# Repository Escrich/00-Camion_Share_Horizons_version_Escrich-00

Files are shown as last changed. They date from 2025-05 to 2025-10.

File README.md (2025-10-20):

# Camion Share Horizons versión Escrich

<br>
<p align="left">
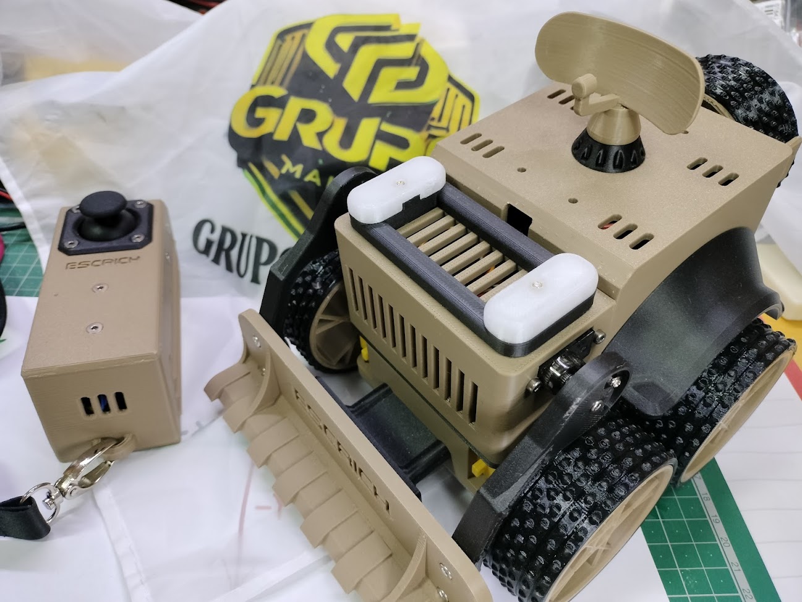
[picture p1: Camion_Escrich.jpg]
Camión Escrich

</p>
<br>

Bueno, tal como prometí, este es el repositorio de GitHub, donde he puesto todas las modificaciones, o al menos las que he recordado, que le he hecho al camión de Share Horizons.

La idea de mejorar, (desde mi punto de vista), el camión, no es porque fuese un mal diseño, sino, porque pensé que había ciertas cosas que con pequeñas modificaciones podrían funcionar aún mejor, 
lo cual era una buena excusa para ponerse a jugar, y crear piezas nuevas y buscarme así, nuevos problemas.

Aquí os traigo los diseños modificados, los he grabado en formato .step, porque es un buen formato de intercambio, que pueden abrir la mayoría de programas de diseño, e incluso directamente los laminadores, 

- 20250603 He añadido imagenes en cada sección, para ver de una manera mas rápida y eficiente, lo que esa sección contiene.
- 20250603 He subido las piezas en formato .stl u .obj, para que sea aún mas facil imprimirlas, recuerda que tu laminador, el que sea, procesa perfectamente los ficheros .obj tal como lo hace con los ficheros .stl.
- 20250603 Mejora de las instrucciones y tareas a efectuar con el mando a distancia.
- 20250827 Actualización del software del camión y del mando a distancia, como consecuencia de las nuevas actualizaciones en las librerías de Arduino.

> [!TIP]
> La mayor parte de la información está en la zona de notas de trabajo, donde la mayoría de las notas  que escribí a mano sobre el papel, las he volcado sobre el PDF original, tambien hay información especifica en cada una de las secciones.

> [!IMPORTANT]
> La sección sobre el nuevo mando a distancia, constituye un nuevo proyecto por si sola, en esa sección, al igual que en muchas otras, hay mucho material didactico, que puede ser muy util a los que estén empezando en el mundo del DIY, así como para ser usado incluso a nivel escolar, o en grupos de formación, he intentado en todo, ser lo mas didactico posible.

> [!NOTE]
> Toda la información del proyecto original, está en:
> 
> https://makerworld.com/es/models/903977#profileId-863654
>
> https://cad.onshape.com/documents/0da7019aae1737c3977f49da/w/1bc25fe6fd6783f9f0ffa83a/e/cbea3b41cde89c5ffeedc16a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
>
> https://www.youtube.com/shorts/hSA0gdp2WEo
>
> https://www.youtube.com/@SHAREHORIZONS

<br>
<br>

- **Bueno, este es un trabajo que he hecho, pensando en que pueda servir de ayuda a los demás, si a alguien le sirve este trabajo, para no perder el tiempo que yo he necesitado perder, aunque sea uno solo, ya me doy por satisfecho, entonces mi objetivo se habrá cumplido, si necesitas ayuda, tienes dudas, o quieres comentar algo al respecto, además de que puedes hacerlo directamente aquí, recuerda que puedes encontrarme en las redes, y que estas son mis direcciones:**

<br>
 
www.github.com/escrich

https://t.me/escrich

https://www.tiktok.com/@josemescrich

https://www.youtube.com/@josem.escrich2610

<sub>
20251020 Jose M. Escrich 
</sub>

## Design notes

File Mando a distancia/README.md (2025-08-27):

# Mando a distancia Escrich

<br>
<p align="left">
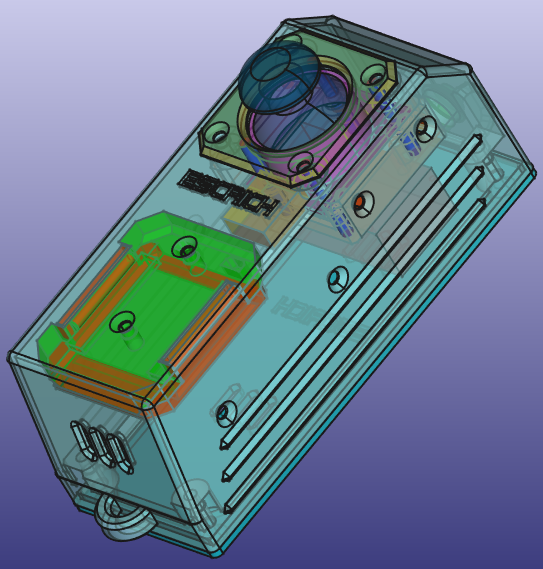
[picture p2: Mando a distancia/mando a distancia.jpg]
Mando a distancia versión Escrich

</p>
<br>

Aquí podeis encontrar toda la información relativa al mando a distancia, desde el programa, lleno de comentarios con los cambios efectuados, y una explicacion de dichos cambios, en la mayoría de los casos, 
hasta las instrucciones de montaje y puesta en marcha, paso a paso.

Tambien están, por supuesto, los ficheros .step de todas las piezas que componen el mando a distancia, así como los ficheros .obj o .stl, pero lo que mas trabajo me ha costado, 
es la guía de construcción, donde se explica paso a paso como construirlo, como y cuando programarlo, y como cablearlo, ajustarlo y hacerlo funcionar.

La forma de programarlo, que está descrita paso a paso, es la descrita en el documento original de **Share Horizons**, y es exactamente la misma que para el **DOIT ESP32 DEV KIT V1**, pero eligiendo una placa, o la otra, ya que el microcontrolador que lleva dentro, 
un **Wemos D1 Mini ESP32**, es **100% compatible**, con el **ESP32** del diseño original.

Programarlo, es tan simple como conectar un cable USB entre tu ordenador y el **Wemos D1 Mini**, cargar el programa que encontrarás aquí, en el entorno **Arduino**, si es que no lo habías hecho antes, 
elegir la placa, (**Wemos D1 Mini ESP32**) y el **puerto correctos**, 
asegurarte de que has puesto la **mac address** de la placa de tu camión correctamente, y pulsar en el entorno **Arduino** el **icono de compilar y cargar**, 
si lo has hecho todo bien, el sistema saldrá andando a la primera, que por otra parte, es lo mas normal.

> [!IMPORTANT]
> 20250827 Actualización del software del mando a distancia, como consecuencia de las actualizaciones de las librerías de Arduino.
>

> [!WARNING]
> Al construir el mando a distancia, no olvides, antes de aplicar tension al Wemos D1 MINI, haber ajustado externamente la fuente de alimentación, para una tensión de salida de entre **5'0 Voltios, y 5'1 Voltios**.
> si no lo haces así, puedes destruir el microcontrolador, al aplicarle una tensión mas alta de la que puede aguantar.

<br>

> [!CAUTION]
> Recuerda alimentar al Joystick con tan **solo 3'3 Voltios**, desde los pines de la placa del Wemos, o ESP32,
> Es un problema muy común, alimentarla a 5 voltios, tal como pone en su serigrafía, haciendolo así, el camión se pondrá en marcha en cuanto conecte con el mando, y notarás una sensación de total falta de control.

<br>
 
www.github.com/escrich
  
https://t.me/escrich
  
https://www.tiktok.com/@josemescrich

<sub> 
20250509 Jose M. Escrich 
</sub>

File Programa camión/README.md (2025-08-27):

# Programa del camión Share Horizons versión Escrich

<br>
<p align="left">
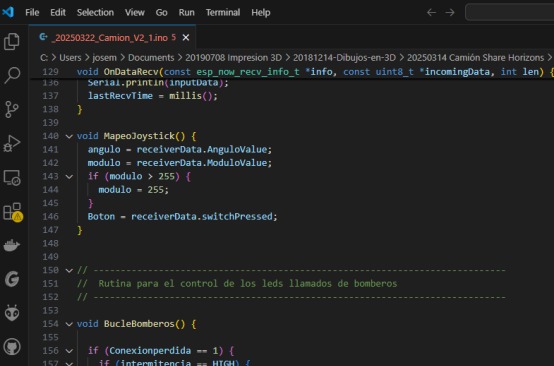
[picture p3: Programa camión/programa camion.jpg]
Programa del Camión

</p>
<br>

Aquí podeis encontrar información relativa al programa del camión, una vez reformado por mi, que insisto, no es mejor ni peor, tan solo diferente al original, y que conserva una buena parte de lo que ya había.

- La forma de programarlo, que está descrita paso a paso, es exactamente la misma para el DOIT ESP32 DEV KIT V1, que para el Wemos D1 Mini ESP32, que es el micro que lleva mi versión del mando a distancia,
  una vez en el entorno Arduino, solo hay que elegir la placa y puerto correctos, hay una buena descrpcion de como hacerlo en las instrucciones del mando a distancia. 

- Por cierto el Wemos D1 Mini ESP32, es 100% compatible, con el ESP32 del diseño original.

- Programarlo es tan simple como conectar un cable USB entre tu ordenador y el ESP32, cargar el programa que encontrarás aquí, en el entorno Arduino, si es que no lo habías hecho antes, 
elegir la placa, (DOIT ESP32 DEV KIT V1) y el puerto correctos, 
y pulsar en el entorno Arduino el icono de compilar y cargar, 
si lo has hecho todo bien, el sistema saldrá andando a la primera, que por otra parte, es lo mas normal.

 - En esta versión se ha cambiado, comprobado y corregido, la nomenclatura de todas las variables de dirección y control de motor, para que coincidan con la dirección en la que se mueve el camión.

 - He recalculado los angulos de la dirección, haciendolos simetricos, tanto a izquierda y derecha, como adelante y atrás.

 - Tambien se han añadido rutinas para el cambio de color de los leds en función de la dirección, que ahora al moverse, hay dos leds de la tira, que se vuelven azules, y que indican en que dirección vamos,
   por eso es importante el orden y la forma de montaje, a la hora de poner la tira led, por otra parte, aunque está hecho para 8 leds, es muy sencillo editarlo para que funcione con los 12 leds del diseño original.

 - Añadidos nuevos leds Neopixel en el canal 5, con los que se hace el efecto de luces de policia, son cuatro leds inteligentes Neopixel, 
  conectados uno a continuación de otro, y programados para hacer ese efecto, con una sección de programa abierta a hacer las combinaciones que quieras, como ya digo en otro sitio, es una versión, muy exportable a cualquier otro proyecto.

 - También puedes desde el mismo programa, sin necesidad de un programa auxiliar, mostrar la dirección Mac Address de tu camión, imprescindible para incluirla en el programa del mando a distancia

 - Otra cosa que tambien he añadido, tanto en el mando como en el camión, es una cosa mas bien estética, el led azul de la placa, ahora,
   se enciende o apaga a cada ciclo de programa, para poder comprobar de manera visual, que el programa está funcionando y no se ha quedado colgado.

> [!IMPORTANT]
> 20250827 Actualización del software del camión, como consecuencia de las actualizaciones de las librerías de Arduino
>

> [!TIP]
> Aunque aquí te deje alguna explicación sobre el software del camión, la mayor parte de las reformas, por no decír todas,
> están comentadas y documentadas con texto y comentarios, dentro del propio programa, (no me gusta llamarle "sketch")
>

<br>

www.github.com/escrich
  
https://t.me/escrich
  
https://www.tiktok.com/@josemescrich

<sub> 
20250509 Jose M. Escrich 
</sub>

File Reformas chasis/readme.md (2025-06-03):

# Reforma del chasis

<br>
<p align="left">
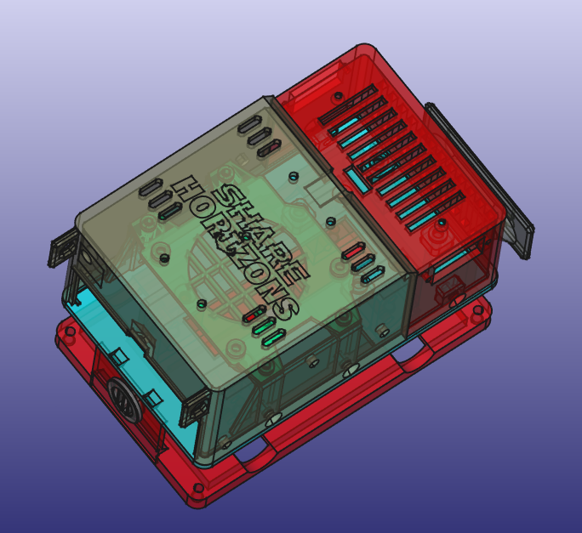
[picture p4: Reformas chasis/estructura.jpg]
Estructura, chasis y demás elementos mecánicos

</p>
<br>

Esta es la parte mas visible, ya que además engloba las las piezas de mayor tamaño, las reformas que he hecho a las diferentes piezas, han sido las siguientes:

- **Chasis V1;** En primer lugar empezamos por el propio chasis, las reformas efectuadas en el han sido varias, la primera, y mas importante, fué suplementar en 3 milimetros la posición de los motores,
  para que queden mas afuera, mejore la estabilidad, e impida que los laterales de las ruedas rocen en la estructura del camión.
  tambien se le ha hecho un pequeño espacio, para poner una matricula, las rejillas originales, que en alguno de los prototipos hemos llegado a romper, y eliminar para poner el interruptor principal,
  interruptor que finalmente hemos montado en otro sitio, son sustituidas por un pequeño tapón en forma de rejilla, que se puede imprimir aparte, y que tambien está incluido en el fichero .step.
  
- **Defensa V1;** Aquí la reforma ha sido tan simple, como añadir un espacio para la matricula delantera, el diseño de la pieza me parece bueno tal como está.

- **Estructura interna;** Aquí el cambio ha sido mayor, en primer lugar se han añadido paredes y angulos, entre las antiguas torretas verticales, que por su posición y forma, eran demasiado fragiles y faciles de romper,
  también se han añadido separadores, para la placa de circuito impreso, en la zona donde se atornilla la placa del driver para los motores, con el objeto de que al atornillarla,
  las soldaduras de las conexiones inferiores, no ejerzan presión contra el plastico de las torretas cuadradas.

- **Rejilla tapón;** Esta es la rejilla descrita anteriormente, para sustituir a la rejilla trasera del chasis, aumenta la resistencia de esa zona, bastante endeble, y permite dar un toque de diferente color.

- **Base ESP32;** Aquí he añadido rejillas para ventilación del ESP32, tambien he cambiado el sistema de insertos metalicos, que ahora se montan por la parte contraria al circuito impreso,
   tambien he diseñado unas pequeñas torretas, para que la parte inferior del circuito impreso, y sus soldaduras, no haga, presión contra la pieza que lo soporta,
   sino que ahora hay un espacio que permite la ventilación, al tiempo que elimina el contacto con la superficie de la propia pieza de soporte.
 
- **Soporte servos;** En esta pieza, los cambios están relacionados con las luces de "Policia", se trata de los taladros para sujetar la estructura de las luces led,
  o cualquier otra cosa, así como la salida de cables de las propias luces, hacia el interior del camión.

- **Carcasa multiusos;** Denominada así por sus multiples taladros para montar cualquier arilugio, así como sus otras peculiaridades, en primer lugar, al montar el soporte del ESP32 girado 180 grados,
  como digo en mis notas, la carcasa tiene un recorte en la parte delantera, que permite, siempre que no esté montado el soporte de servos, conectar y cambiar el programa del ESP32,
  aunque esta carcasa esté puesta, con lo que se ahorra desmontar todas las ruedas, y quitar la carcasa, para introducir cambios en el programa, pensé también en usar una conexión OTA, pero eso de momento está parado.

  Otra caracteristica importante son las multiples rejillas de ventilación, ya que por su forma de cúpula, tiende a almacenar el calor en la zona del ESP32, con las rejillas se evita, al menos en parte, este efecto.

  tambien tiene en la parte trasera dos protecciones, una a cada lado, que protegen el interruptor de palanca, y la toma para poder cargar la batería sin tener que abrir la puerta o el camión,
  simplemente, se conecta la clavija del cargador, con el interruptor en la posición de apagado, y se pone en marcha el cargador.

  Con el fin de poder usar interruptores de palanca, para taladro de 6 mm., he añadido un separador, que se monta internamente, y hace que el interruptor asome lo justo como para ponerle la tuerca.
 
- **Placa motores;** Por ultimo, para los que ya tengan el camión impreso, he añadido esta pequeña placa con dos taladros, de la que hay que imprimir cuatro unidades, y que se monta en el diseño original,
  entre cada motor y el chasis, y que hace de suplemento, para conseguir separar las ruedas del chasis, tal como describía al principio de este texto. 

<br>

www.github.com/escrich
  
https://t.me/escrich
  
https://www.tiktok.com/@josemescrich

<sub> 
20250510 Jose M. Escrich 
</sub>

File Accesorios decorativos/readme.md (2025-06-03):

# Accesorios añadidos o modificados

<br>
<p align="left">
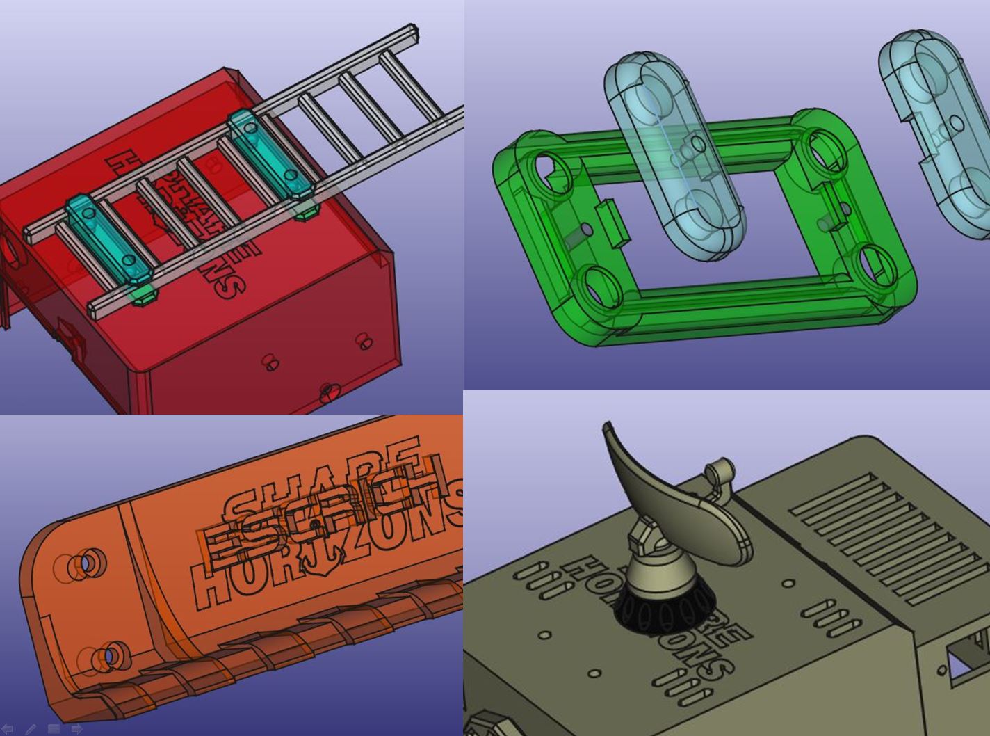
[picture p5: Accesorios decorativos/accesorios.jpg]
Accesorios decorativos

</p>
<br>

### Pala excavadora

Esta pala se basa totalmente en el diseño original, tan solo se le han añadido los dientes, y se han movido hacia el centro los dos grupos de taladros de sujección, disminuyendo la distancia entre taladros en ocho milimetros, 
esta diferencia de ocho milimetros de envergadura, proviene de un exceso en la medida original, y del hecho de haber rebajado el brazo del servo, por el lado contrario al piñon, hasta dejarlo plano.

En ambos camiones está impresa en Super PLA plus.

### Escalera de bomberos

La escalera es para aprovechar el color rojo de uno de mis dos camiones, para darle un aspecto similar al de un camión de bomberos, lejos de pretender una recreación realista, es mas bien algo conceptual, o casi un elemento de comic,
junto a la escalera están los soportes que la sujetan y acompañan, en los soportes de la parte superior, se montan insertos metálicos de M3 usando calor, estos insertos, se montan desde lo que sería la parte superior, 
por contra el tornillo que los sujeta, viene desde dentro de la carcasa del camion, haciendo, según mi practica habitual, que los insertos queden de forma antagonista al tornillo,
y que no sea posible arrancarlos, por mas que se apriete el mencionado tornillo, sino que la tendencia, sea a clavarse cada vez mas en la pieza, evitando que se pueda soltar, 
aquí no es necesaria, quizás, tanta sujección, pero es mas un modo de trabajar que aplico siempre que es posible, a todos los insertos metálicos que monto en mis diseños.

La escalera y sus piezas de sujección, han sido impresas en PETG.

### Antena de telecomunicaciones

La antena es solo un adorno que dibujé hace años, como parte de los diseños para un barco de RC, y al igual que en el caso de la escalera es solo un concepto, poco realista, pero entendible, de lo que es una antena
lleva en su interior un inserto metalico de M3, montado a la manera tradicional, para no dejar un taladro visible desde la parte superior, y una pieza decorativa circular como base, 
se atornilla tambien desde dentro del camión, usando la carcasa modificada, que denomino carcasa multiusos, y que tiene ya preparados los taladros para la escalera, la antena o cualquier otro uso que la imaginación te sugiera.

La antena está impresa en Super PLA plus, y la pieza decorativa de la base en PLA con fibra de carbono, (PLA CF).

### Rotativo luminoso

Aunque no hay ningún tipo de rotación mecanica, se trata de un rotativo como el de una ambulancia, o coche de bomberos, donde la sensación de rotación se consigue con el movimiento aparente, que se logra encendiendo y apagando leds del tipo Neopixel,
para ello en el programa se ha añadido un nuevo canal Neopixel, usando D5 como salida de control, y se ha implementado con cuatro leds independientes, no en una tira led, cableados uno a continuación del otro, 
el "rotativo" hace tres funciones diferentes, las dos primeras muy similares, en caso de no haber conexión con el mando, mediante una rutina simple se encienden en rojo, dos a dos, los dos leds delanteros, o los dos traseros, mientras los otros dos permanecen apagados,
una vez que se produce la conexión entre el camión y el mando a distancia, la rutina es la misma, pero esta vez con la luz en verde.
La diferencia real viene al poner los motores en marcha, aquí la estructura del programa es diferente a los dos casos anteriores, y se pueden programar facilmente, multiples pasos con multiples combinaciones de luces y colores, simplemente añadiendo subestructuras case / break,
una vez estas se agoten, el programa simplemente saldrá y si las condiciones se mantienen, volverá a ejecutar toda la secuencia de colores desde el principio.

Tras muchas pruebas, poner luces en plan "coche fantastico", y hacer muchas combinaciones, al final solo hay dos combinaciones de rojo y azul, que se alternan entre si, con lo que el programa de luces en movimiento solo tiene dos pasos, a pesar de mantener la estructura para poder crear multiples pasos y cambios de luz, lo que la convierte en una estructura de programa, facilmente exportable, para poder ser utilizada en otros proyectos.

Todo el conjunto va sujeto con dos tornillos de M2'5, que vienen desde la pieza de soporte de los servos, previamente modificada, con los taladros de sujección y la salida de cables hacia el interior del camión, los insertos de M2'5, se montan en las dos piezas transparentes/translucidas, desde la parte de arriba, para ser atornilladas desde abajo, siguiendo la misma filosofia explicada previamente para los insertos.

Las luces propiamente dichas, en ambos camiones, están impresas en Transparent PETG, y los soportes, en el caso del camión de bomberos es PETG, pero en el caso del camióncito con antena, se trata de nuevo de PLA CF.

### Tapa leds gruesa

Es la misma tapa original, pero aumentada en grosor en un 50%

Está impresa en un solo color, usando transparent PETG

<br>

www.github.com/escrich

https://t.me/escrich

https://www.tiktok.com/@josemescrich

<sub> 
20250510 Jose M. Escrich 
</sub>

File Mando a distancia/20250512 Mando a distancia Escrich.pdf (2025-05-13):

# 20250512 Mando a distancia Escrich

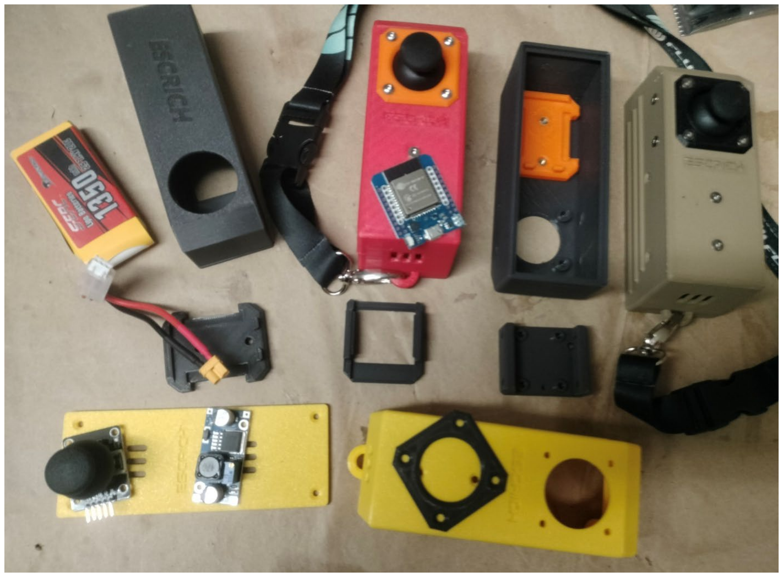
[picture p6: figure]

## Teoría e instrucciones para el mando a distancia multiusos

13/05/2025 | 1 20250512 Mando a distancia Escrich
www.github.com/escrich

## Orientación del Joystick

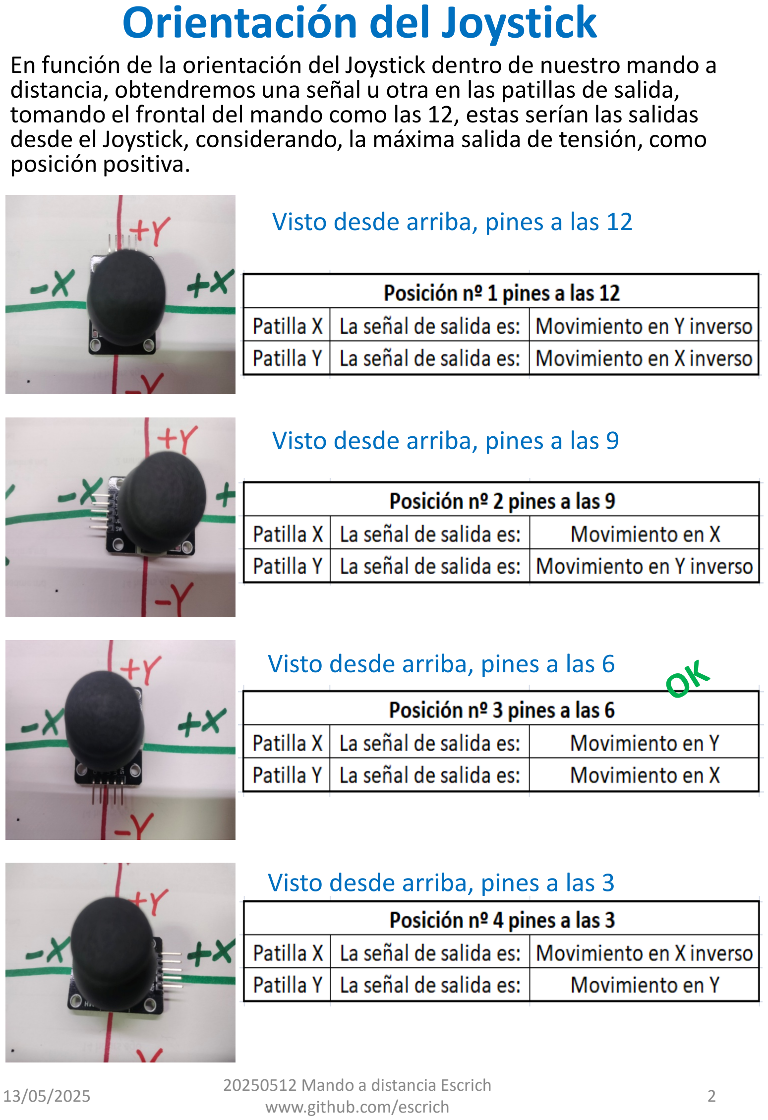
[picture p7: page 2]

Visto desde arriba, pines a las 12

13/05/2025 | 2 20250512 Mando a distancia Escrich

Visto desde arriba, pines a las 9

Visto desde arriba, pines a las 6

Visto desde arriba, pines a las 3

En función de la orientación del Joystick dentro de nuestro mando a distancia, obtendremos una señal u otra en las patillas de salida, tomando el frontal del mando como las 12, estas serían las salidas desde el Joystick, considerando, la máxima salida de tensión, como posición positiva.

## Orientación del Joystick

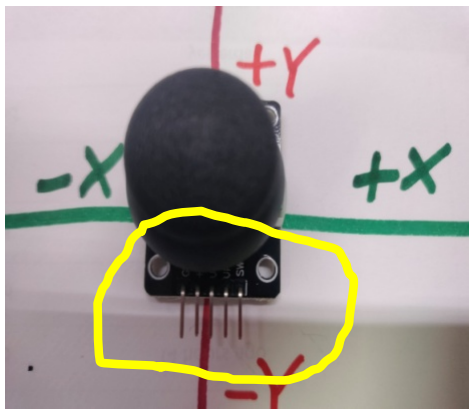
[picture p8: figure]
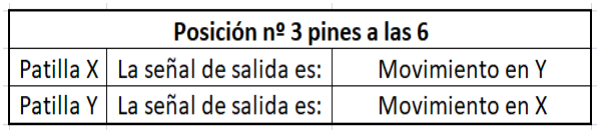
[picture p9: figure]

13/05/2025 | 3 20250512 Mando a distancia Escrich

Al montar los pines mirando hacia nosotros, podemos ver que las funciones de X e Y están intercambiadas, por lo que, o bien las invertimos en el programa, o bien, intercambiamos los cables, para mayor claridad y para poder mantener los mismos esquemas, he optado por hacer los cambios en el programa

Visto desde arriba, pines a las 6

## Conexión del Joystick

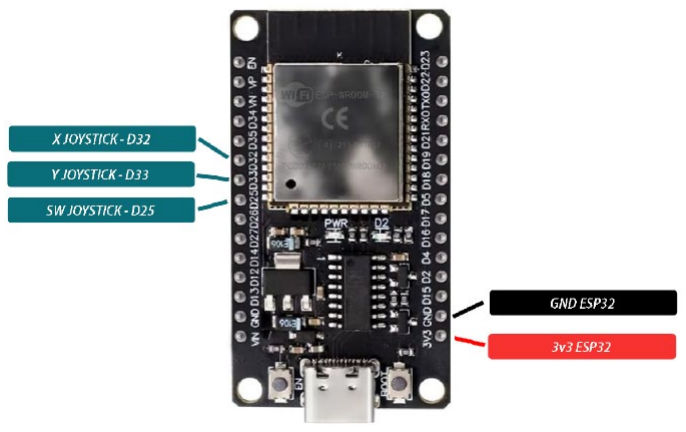
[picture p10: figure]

13/05/2025 | 4 20250512 Mando a distancia Escrich

Por tanto las conexiones quedarían tal como se muestran en las instrucciones de Share Horizons.

Esquema original Share Horizons.

## Conexión del Joystick

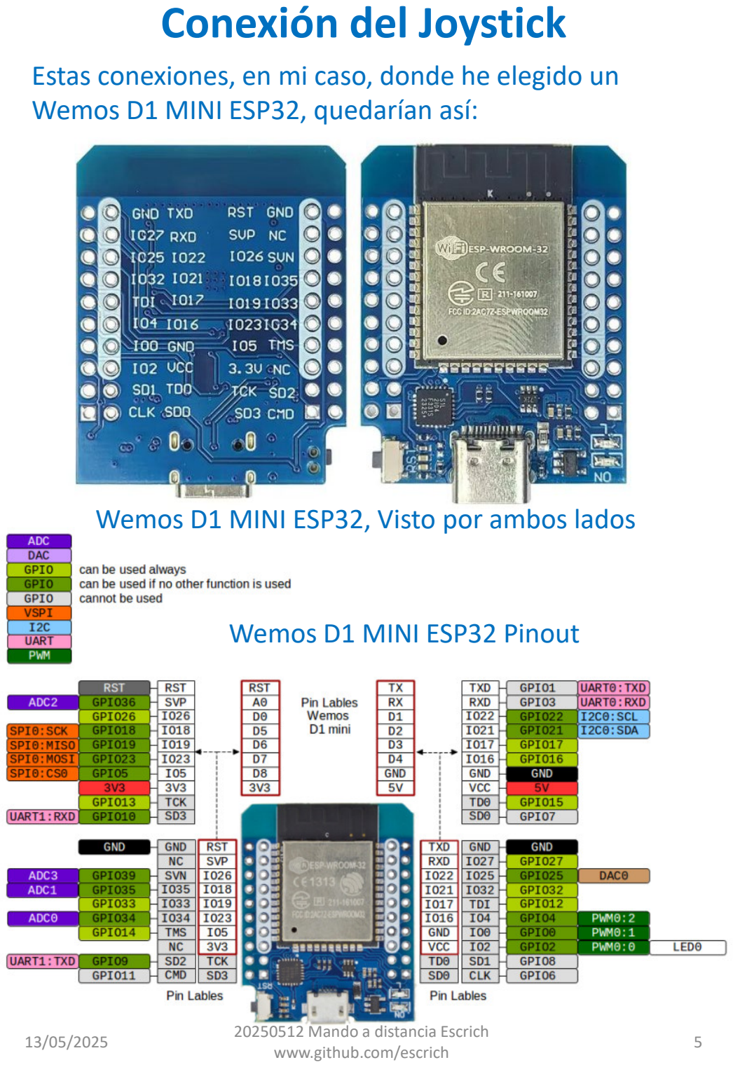
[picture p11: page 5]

13/05/2025 | 5 20250512 Mando a distancia Escrich

Estas conexiones, en mi caso, donde he elegido un Wemos D1 MINI ESP32, quedarían así:

Wemos D1 MINI ESP32 Pinout

Wemos D1 MINI ESP32, Visto por ambos lados

## Conexión del Joystick

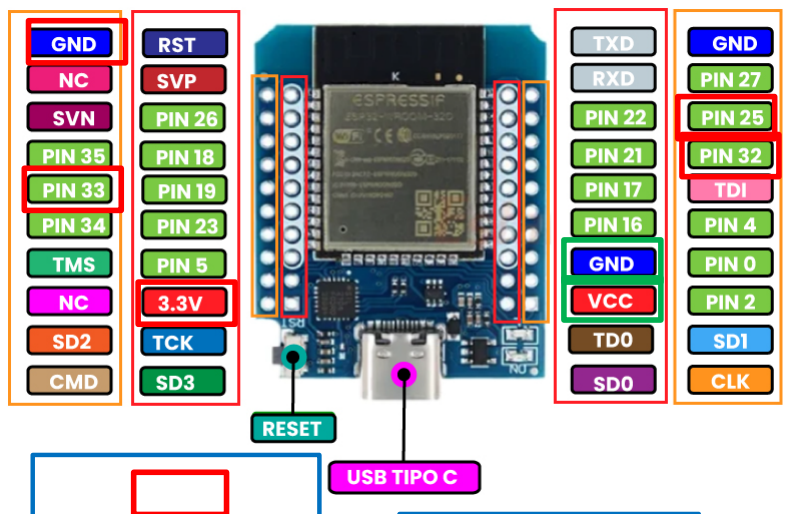
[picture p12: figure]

13/05/2025 | 6 20250512 Mando a distancia Escrich

Estas conexiones, en mi caso, donde he elegido un Wemos D1 MINI ESP32, quedarían así:

Esquema de conexiones

Conexiones al joystick:
D32: EJE X
D33: EJE Y
D25: Switch joystick
GND: Negativo
3.3V: Positivo

Alimentación a la placa:
GND: Negativo
VCC: + 5 Voltios

Haciendo las conexiones según estas instrucciones el mando a distancia es 100% compatible con la versión original de Share Horizons.

## Alimentación del Joystick

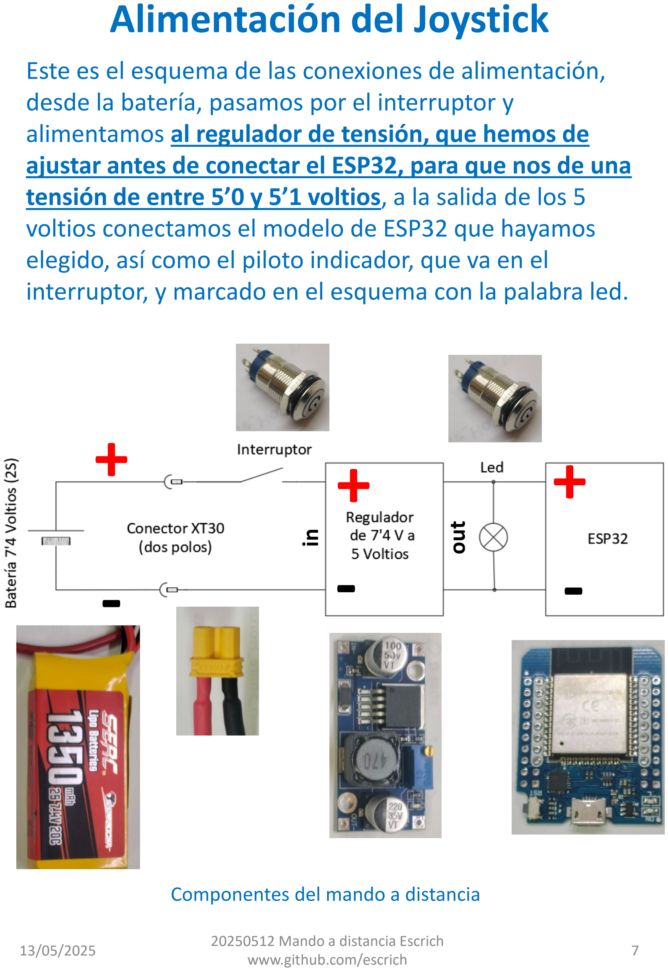
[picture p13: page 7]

13/05/2025 | 7 20250512 Mando a distancia Escrich

Este es el esquema de las conexiones de alimentación, desde la batería, pasamos por el interruptor y alimentamos al regulador de tensión, que hemos de ajustar antes de conectar el ESP32, para que nos de una tensión de entre 5’0 y 5’1 voltios, a la salida de los 5 voltios conectamos el modelo de ESP32 que hayamos elegido, así como el piloto indicador, que va en el interruptor, y marcado en el esquema con la palabra led.

Componentes del mando a distancia

+ | + | +

in

out

## Montaje del mando a distancia

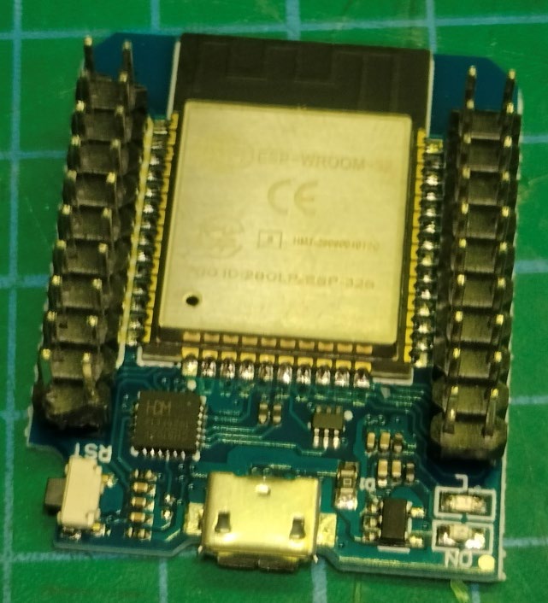
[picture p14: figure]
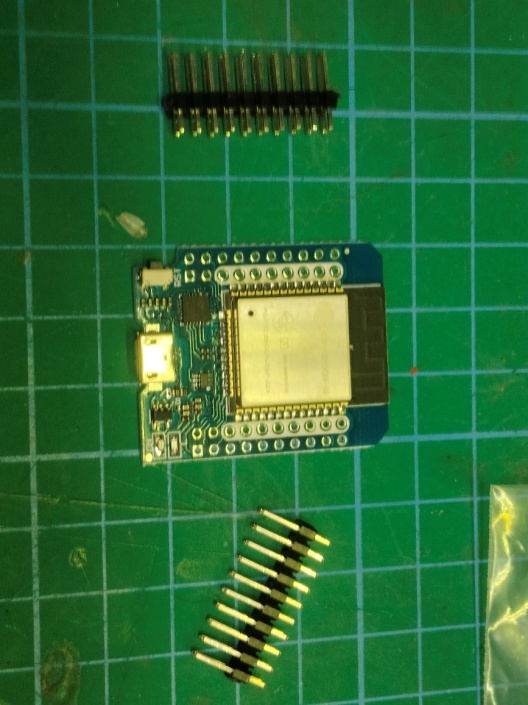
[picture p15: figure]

13/05/2025 | 8 20250512 Mando a distancia Escrich

Lo primero que se necesita, son dos tiras dobles de 10 pins x 2, soldamos las dos tiras de pins de dos filas por la parte de debajo del Wemos, de manera que los pins, para conectar, sobresalgan por el lado donde está el chip principal

Wemos D1 Mini ESP32 con las tiras de pins ya montadas.

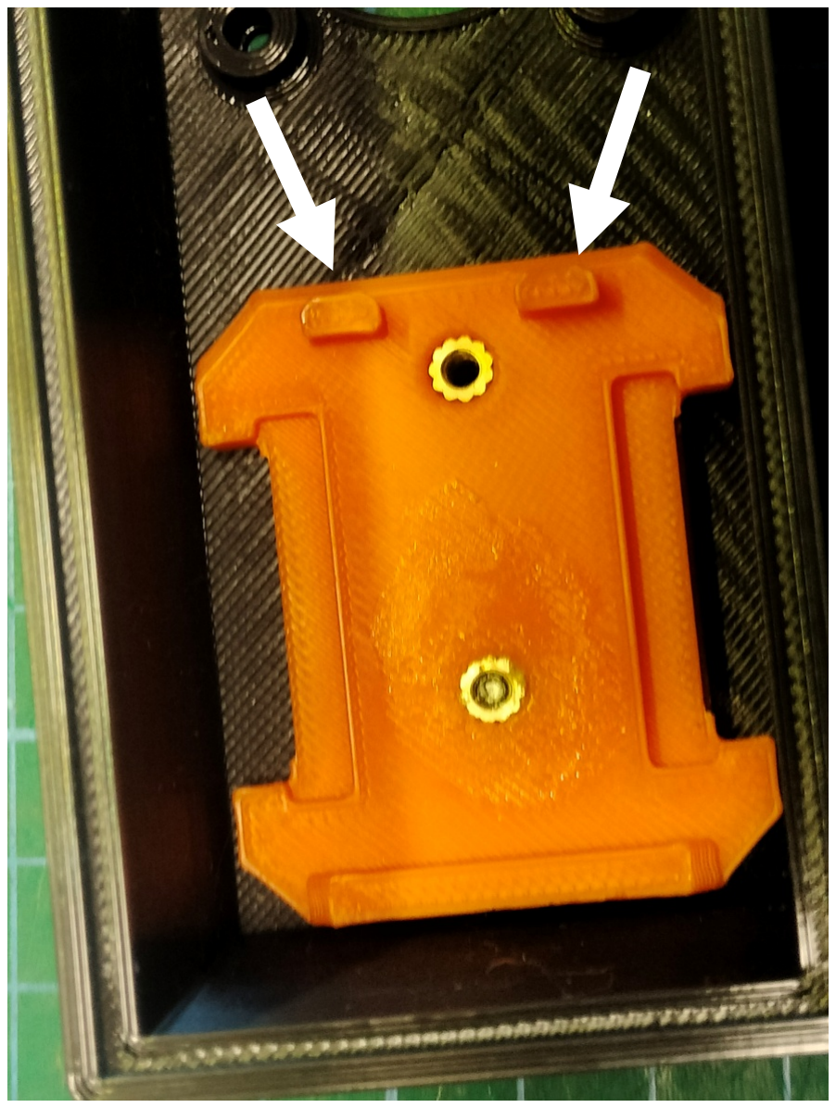
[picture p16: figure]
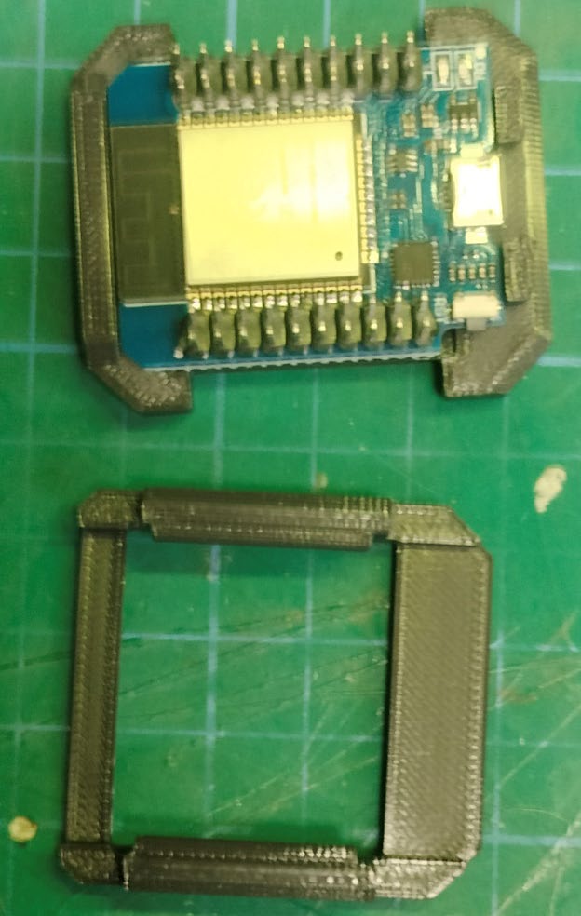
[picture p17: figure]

13/05/2025 | 9 20250512 Mando a distancia Escrich

El Wemos D1 Mini ESP32, se sujeta a la caja del mando a distancia, mediante un sistema de clip, por eso, lo primero que hemos de hacer, es sujetar la pieza del clip que lleva dos insertos metálicos, los insertos se montan desde el lado donde luego se coloca el Wemos, por eso tienen que quedar mas bajos que la superficie de plástico Una vez montados los insertos, se sujeta a la caja mediante tornillos de cabeza plana, los dos pequeños montículos van hacia el frontal del mando.

El Wemos se monta con el
conector USB mirando hacia los dos montículos, y se monta la pieza superior, hasta que ambos lados hagan click y la pieza de cierre quede
horizontal.

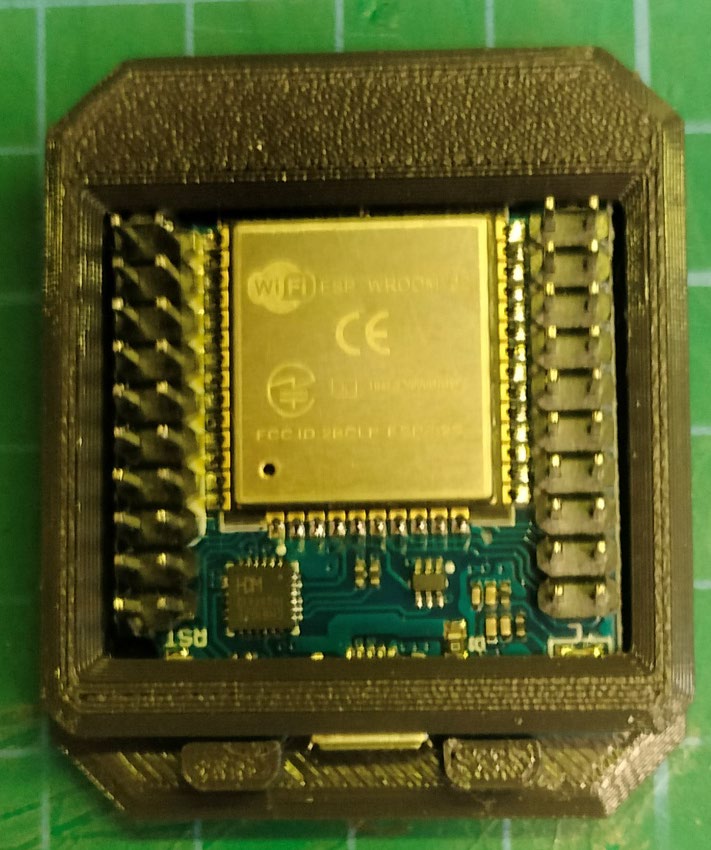
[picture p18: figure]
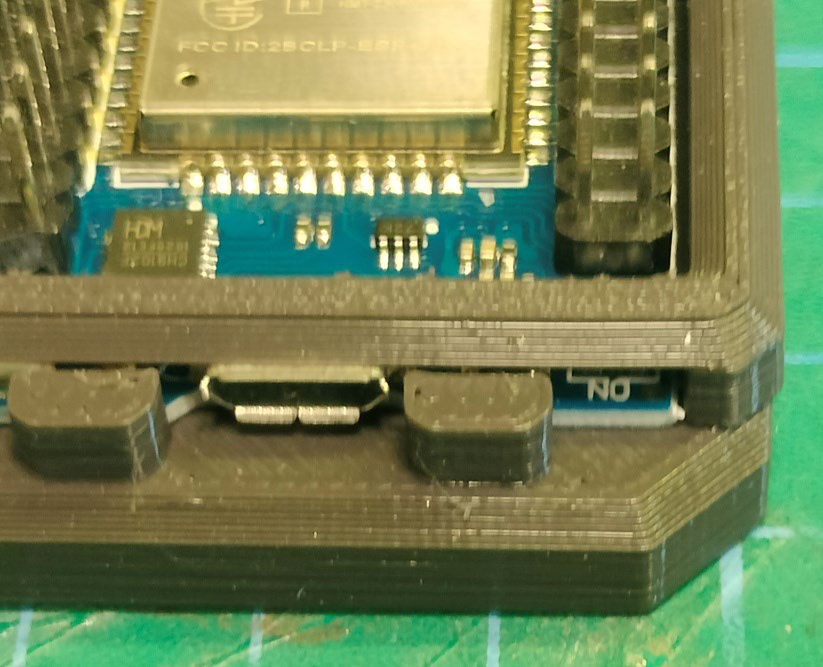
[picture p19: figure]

13/05/2025 | 10 20250512 Mando a distancia Escrich

Así quedaría una vez cerrado, el conector USB queda accesible y mirando hacia el centro del mando, de todas maneras, mi recomendación es cargar el software tras haber soldado los pines y antes de sujetarlo a la caja del mando

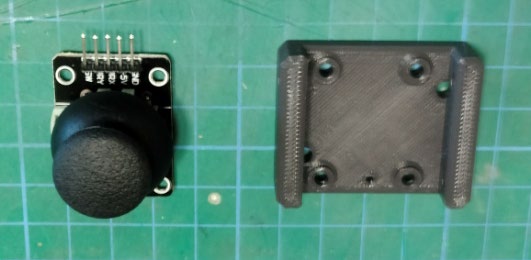
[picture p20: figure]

13/05/2025 | 11 20250512 Mando a distancia Escrich

Una vez sujeto el Wemos, hemos de sujetar el joystick

Hay que montar los insertos desde la parte de abajo, en esta cara hay que montar 6 insertos, el joystick va en el lado contrario, el pequeño taladro, marca la posición de montaje, hacia el frontal del mando, este mismo taladro marca la posición de la tapa de la caja. En los laterales de la misma pieza, se montan 4 insertos mas, esta vez a la manera clásica.
Esta sería la posición de montaje, con los pines hacia el centro del mando y el taladro hacia la parte frontal de este.
Si están todos los insertos montados, esta sería su posición para ser atornillado.

El regulador de tensión, se monta en la parte inferior del soporte del joystick, de manera que su electrónica queda visible al abrir la tapa del mando

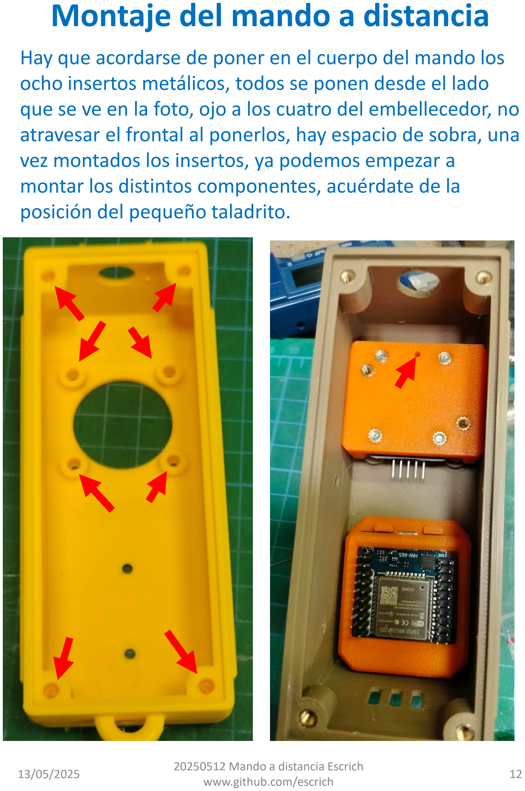
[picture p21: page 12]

13/05/2025 | 12 20250512 Mando a distancia Escrich

Hay que acordarse de poner en el cuerpo del mando los ocho insertos metálicos, todos se ponen desde el lado que se ve en la foto, ojo a los cuatro del embellecedor, no atravesar el frontal al ponerlos, hay espacio de sobra, una vez montados los insertos, ya podemos empezar a montar los distintos componentes, acuérdate de la posición del pequeño taladrito.

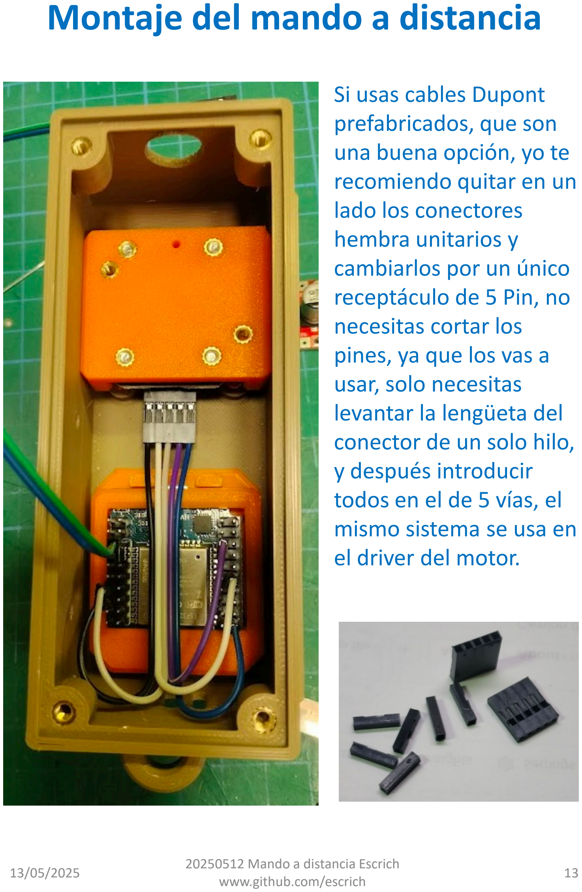
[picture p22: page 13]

13/05/2025 | 13 20250512 Mando a distancia Escrich

Si usas cables Dupont
prefabricados, que son
una buena opción, yo te
recomiendo quitar en un
lado los conectores
hembra unitarios y
cambiarlos por un único
receptáculo de 5 Pin, no
necesitas cortar los
pines, ya que los vas a
usar, solo necesitas
levantar la lengüeta del
conector de un solo hilo,
y después introducir
todos en el de 5 vías, el
mismo sistema se usa en
el driver del motor.

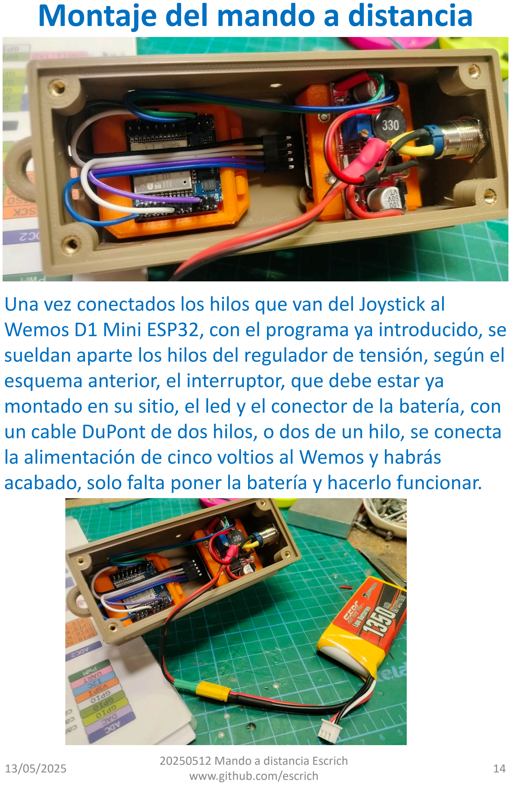
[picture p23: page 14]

13/05/2025 | 14 20250512 Mando a distancia Escrich

Una vez conectados los hilos que van del Joystick al
Wemos D1 Mini ESP32, con el programa ya introducido, se sueldan aparte los hilos del regulador de tensión, según el esquema anterior, el interruptor, que debe estar ya montado en su sitio, el led y el conector de la batería, con un cable DuPont de dos hilos, o dos de un hilo, se conecta la alimentación de cinco voltios al Wemos y habrás acabado, solo falta poner la batería y hacerlo funcionar.

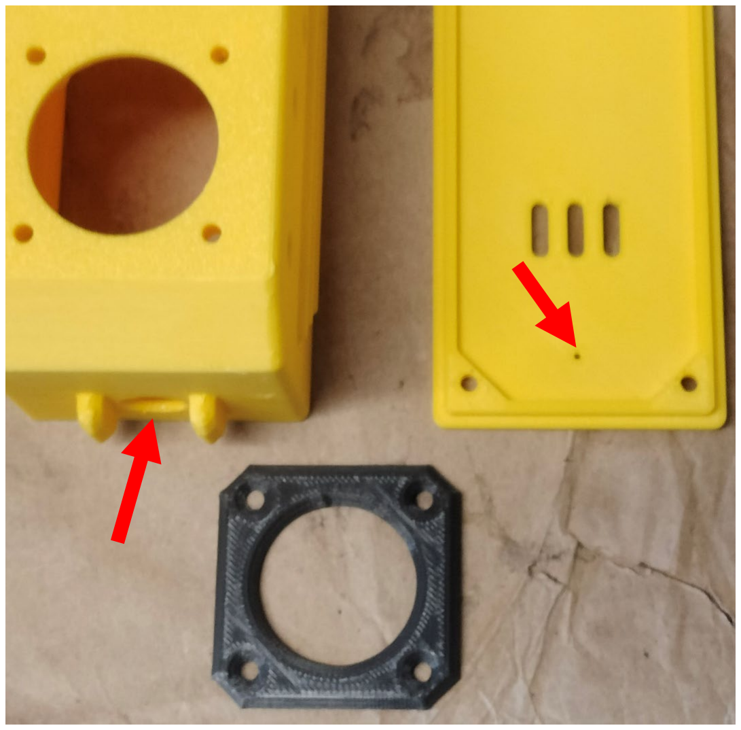
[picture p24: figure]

13/05/2025 | 15 20250512 Mando a distancia Escrich

El taladro previsto en la caja del mando para el interruptor, es suficientemente pequeño, para poder montar casi cualquier interruptor de cuerpo cilíndrico, antes de soldar cables, comprueba que puedes montar tu interruptor, o que necesitas agrandarlo, el máximo taladro practicable es de 12 milímetros de diámetro, si el tuyo es mayor, recuerda modificar en el diseño, la posición de los dos protectores anti golpes para el interruptor, recuerda también, que la tapa inferior, tiene un pequeño taladro, que indica que esa parte va hacia el frente del mando, hacia el interruptor, el embellecedor del joystick se monta desde fuera, al final, cuando todo lo anterior está terminado.

## Programación del mando a distancia

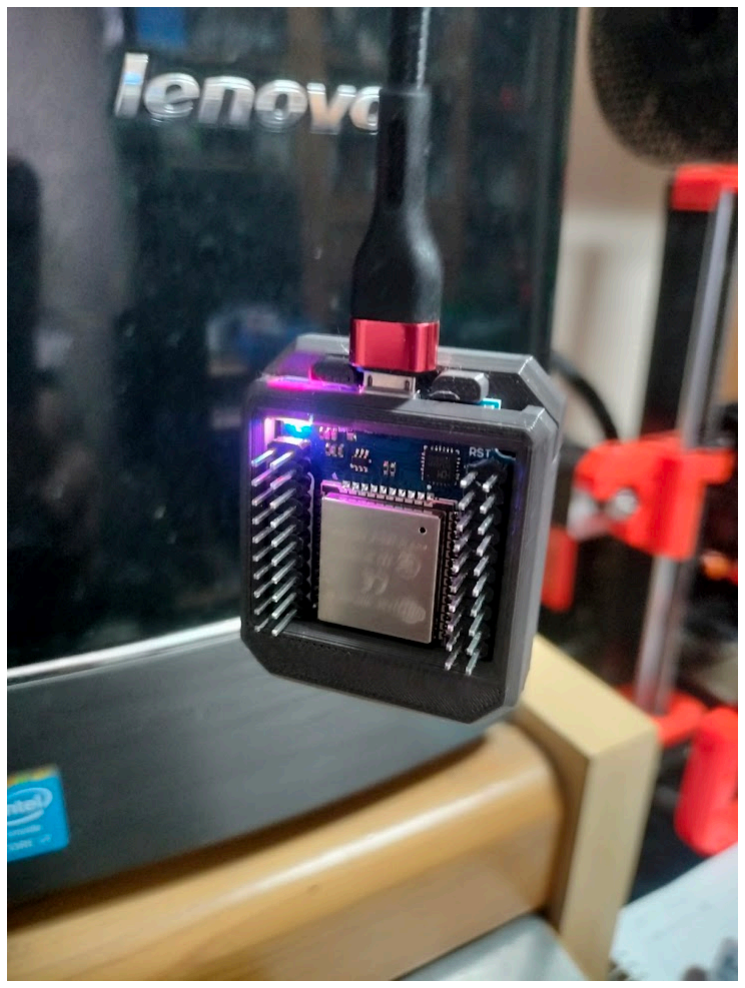
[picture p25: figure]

13/05/2025 | 16 20250512 Mando a distancia Escrich

Para poder programar el mando a distancia se necesita tener funcionando el entorno Arduino, tal y como se describe en el proyecto original de Share Horizons, por lo que no lo voy a describir de nuevo, lo primero es conectar el Wemos a nuestro ordenador mediante un cable USB adecuado.

## Programación del mando a distancia


13/05/2025 | 17 20250512 Mando a distancia Escrich

Una vez conectado mediante el cable USB, abrimos el entorno Arduino, cargamos el programa del mando a distancia, que puedes encontrar junto a este documento, y elegimos la placa y el puerto que vamos a utilizar, la placa debe ser la misma que en mi caso, el puerto es muy probable que sea diferente, comprobamos que hemos puesto la Mac Address de nuestro camión correctamente.

## Programación del mando a distancia


13/05/2025 | 18 20250512 Mando a distancia Escrich

Tras asegurarnos de la dirección correcta de nuestro camión, pulsamos el botón de compilar y cargar, y el sistema nos mostrará esta ventanita.

NOTA: En condiciones normales, no es necesario pulsar los botones de Boot o Reset. Sobre la placa del microcontrolador, solo pulsar el icono y el sistema hace el resto, en el extraño caso de que no sea así, prueba a pulsarlos siguiendo las instrucciones, que ya proporciona Share Horizons

## Programación del mando a distancia


13/05/2025 | 19 20250512 Mando a distancia Escrich

Si todo ha ido bien, que es lo normal, cuando acabe de programar y resetée el microcontrolador, podrás pulsar en Monitor Serie, y verás algo similar a esto.
Enhorabuena, ya tienes el mando a distancia funcionando.

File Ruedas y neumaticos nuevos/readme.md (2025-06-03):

# Ruedas nuevas

<br>
<p align="left">
Ruedas nuevas, llantas y dos modelos de cubiertas
</p>
<br>

En este conjunto aparecen las ruedas diseñadas especificamente para el camión, en el se puede encontrar lo siguiente:

- Un separador para montar la quinta rueda en la parte trasera, como una rueda de repuesto.

- La llanta, preparada para un tornillo de M2'5, pero que tambien se puede montar en un eje con rosca de M3, esta llanta está preparada para montar diferentes cubiertas,
  y debido al ajuste que lleva, y a los dos aros de la superficie, permite montar las cubiertas de TPU, sin necesidad de ningun tipo de pegamento, sin que por ello las cubiertas se salgan o se giren,
  yo siempre recomiendo no tocar en el slicer los parametros de expansion, que la gente en general modifica cuando tiene que hacer una pieza que debe encajar dentro de otra, ya que me parece incorrecto,
  porque los ajustes, tolerancias y demás, han de ser tenidos en cuenta durante el diseño, para que en el momento de imprimir, tu impresora esté correctamente ajustada para darte las medidas que le pides,
  y que te reproduzca fielmente lo que viene en el diseño.

  El brazo de la llanta, hace a su vez la función de mangón de refuerzo del eje del motor cubriendolo completamente y armándolo,
  es absolutamente imprescindible, si hay que roscar en el eje, como así hay que hacerlo, comprobar si está debidamente roscado, y si no es así, pasar los correspondientes machos de roscar,

  no te la juegues tratando de roscar los ejes de plastico de los motores usando un tornillo, porque en el mejor de los casos vas a estropear la rosca, y en el peor vas a romper el eje,
  los motores de eje metálico, los azules, suelen venir roscados a M2'5, o a M3, dependiendo de quien te lo suministre.

  En mi camióncito con antena, la llanta está hecha con PLA Plus, pero tengo otras unidades hechas en PETG, en ambos casos funcionan perfectamente.

- Cubierta de bolas, es la que he montado en mi camioncito con antena, es plana para tener la mayor superficie de contacto posible, y al mismo tiempo,
  con bolitas, a modo de tacos, para que agarre mejor en cualquier superficie, las bolitas, en lugar de cualquier otra forma de tacos, hacen que se pueda imprimir sin necesidad de soportes,
  para montarla no es necesario usar ningun tipo de pegamento, va simplemente deslizada en la cubierta y los aros sirven, además, para su correcto posicionamiento lateral.

  Está hecha en TPU de 95A.
  
- Cubierta de carretera, al igual que la anterior, es plana para tener la mayor superficie de contacto posible, el diseño sin demasiados salientes o hendiduras,
  hacen que se pueda imprimir sin necesidad de soportes,
  para montarla no es necesario usar ningun tipo de pegamento, va simplemente deslizada en la cubierta y los aros sirven, además, para su correcto posicionamiento lateral.

  Está hecha en TPU de 95A.

<br>

www.github.com/escrich
  
https://t.me/escrich
  
https://www.tiktok.com/@josemescrich

<sub> 
20250509 Jose M. Escrich 
</sub>

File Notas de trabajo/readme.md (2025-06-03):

# Notas de trabajo

<br>
<p align="left">
Notas de trabajo
</p>
<br>

Estas son mis notas, escritas a mano sobre el PDF del proyecto original, algunas las he ido pasando a limpio y las he reflejado sobre el propio PDF, que ha quedado un poco caotico, también he completado el documento, 
con instrucciones que pueden ayudar a quien esté pensando en construir el famoso camioncito, 
para que le sea fácil y divertido, de paso, he añadido instrucciones acerca del uso y funcionamiento de las tiras de led Neopixel, 
y alguna que otra cosa mas, este documento sigue vivo, y puede cambiar en cualquier momento.

<br>

www.github.com/escrich
  
https://t.me/escrich
  
https://www.tiktok.com/@josemescrich

<sub> 
20250510 Jose M. Escrich 
</sub>

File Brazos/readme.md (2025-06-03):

# Brazos reforzados

<br>
<p align="left">
Versiones brazos, evolución
</p>
<br>

En este conjunto aparece el brazo original del lado derecho como referencia, solo he puesto los brazos del lado derecho por claridad, 
generar el brazo izquierdo es tan simple como hacer un "mirror", (espejo), en cualquier programa de CAD, o en el propio slicer, todos son capaces de hacerlo.

En primer lugar está el brazo original, para poder comparar, después, viene la primera versión del brazo modificado, 

- Brazo derecho nuevo reforzado corredera corta (1): Este brazo, es totalmente compatible con el original, al igual que cualquiera de los otros, en primer lugar se ha modificado el grosor y la forma,
  para conseguir mayor rersistencia, los insertos metalicos, se montan desde el lado opuesto a la pala excavadora, eso es así en mis tres modelos, tambien se ha hecho mas corta la corredera del tornillo de seguridad,
  que sujeta este brazo al brazo del servo, con esto se consigue que haya mas material entre el final de la corredera y el exterior del propio brazo, ya que este es tambien un punto debil en el brazo original, tambien se redondean los extremos haciendo chaflanes,
  en lugar de dejar las puntas cuadradas, este es el brazo montado en el camión de bomberos.

- Brazo nuevo con dibujo corredera corta opuesta (2): En este brazo, se cambia definitivamente la corredera al lado contrario, eliminando los puntos debiles entre el eje del servo y el resto del brazo,
  la corredera sigue sin ser tan larga como la original, ya que no es necesaria tanta longitud, y aún se puede reducir mas,
  se le añaden tambien unas hendiduras, que además de decorativas, crean perimetros que contribuyen a la rigidez y resistencia del brazo, se mantienen las mejoras creadas en el brazo anterior.

- Brazo derecho corredera corta opuesta y tornillos simulados (3): Este brazo, es en esencia el mismo que el numero 2, con unos elementos para mejorar la estetica, unos tornillos simulados, que pueden imprimirse en otro color,
  la rigidez mecánica, al haber cubierto los taladros con los falsos tornillos, es ligeramente superior, este es el brazo montado en el camión con antena.

En el caso del camión de bomberos, los brazos están impresos en PETG, y en el camioncito con antena, están hechos con PLA CF.

<br>

www.github.com/escrich

https://t.me/escrich

https://www.tiktok.com/@josemescrich

<sub> 
20250509 Jose M. Escrich 
</sub>

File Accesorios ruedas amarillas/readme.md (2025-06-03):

# Accesorios ruedas amarillas

<br>
<p align="left">
Accesorios ruedas amarillas
</p>
<br>

Aquí se incluyen los siguientes elementos:

- Un centrador para taladrar las ruedas amarillas en el punto correcto, este componente es solo un util, que no ha de montarse en ninguna parte del camión.

- Un tapacubos, que ha de imprimirse en PETG, para que apoye el tornillo que sujeta el conjunto, e impide que se salga la rueda.

- Un espaciador interno, que conviene cortar a medida, ya que el interior de las ruedas amarillas tiene variaciones de profundidad entre unas y otras, es un tope interno que impide que la rueda se acerque demasiado al chasis, y permite al mismo tiempo,
  apretar correctamente el tornillo de sujección, esta pieza ha de ser impresa en PETG.

- Un mangón para la rueda que permite alejarla del chasis, al tiempo que hace tope, y refuerza el conjunto del eje del motor y la parte de conexión de la propia rueda, haciendo que todo el conjunto sea mas robusto, esta pieza ha de ser impresa en PETG.

<br>

www.github.com/escrich

https://t.me/escrich

https://www.tiktok.com/@josemescrich

<sub> 
20250509 Jose M. Escrich 
</sub>

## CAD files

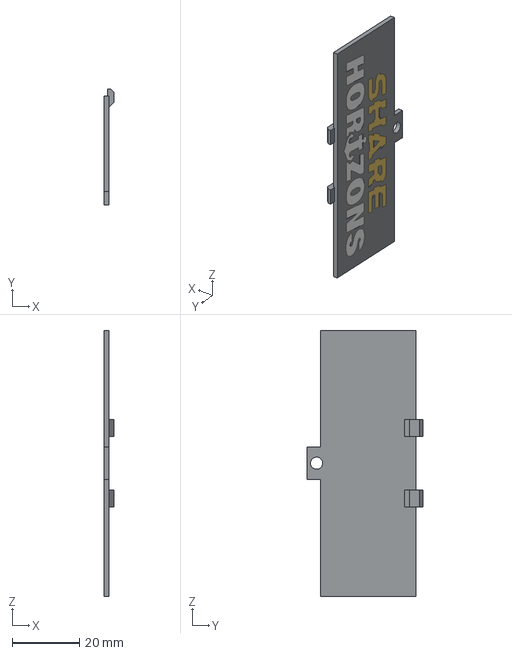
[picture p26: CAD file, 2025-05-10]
Piezas no reformadas/CAMION - TAPA_TRASERA.step
3.00 x 34.4 x 79.1 mm

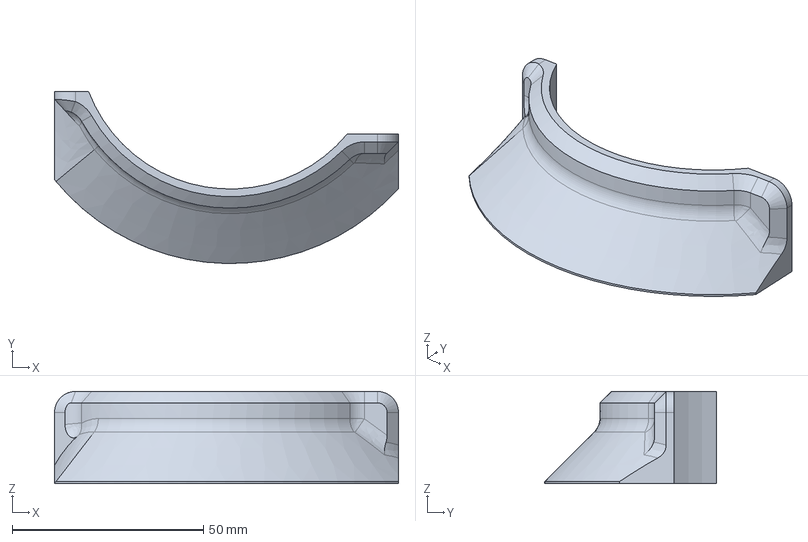
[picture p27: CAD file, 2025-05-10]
Piezas no reformadas/CAMION - GUARDABARROS IZQDO.step
90.0 x 45.0 x 24.1 mm

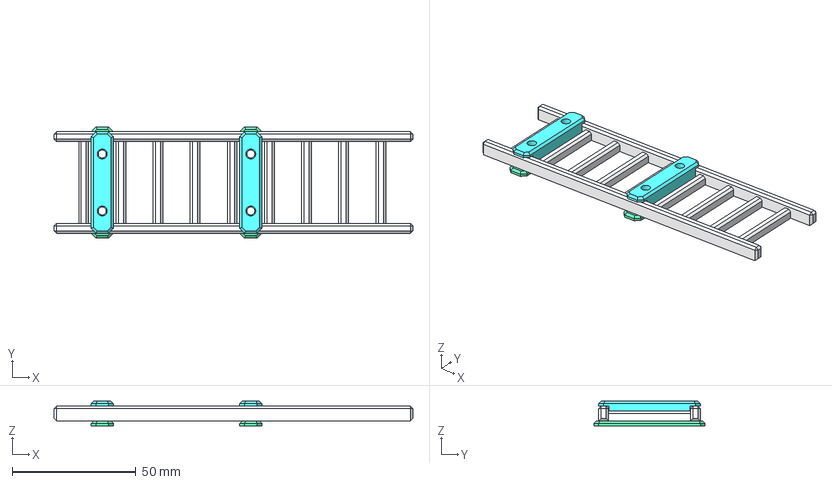
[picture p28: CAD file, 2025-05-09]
Accesorios decorativos/20250319 Escalera camioncito.step
145.0 x 45.0 x 10.0 mm
escalera
soporte abajo x 2
soporte arriba x 2

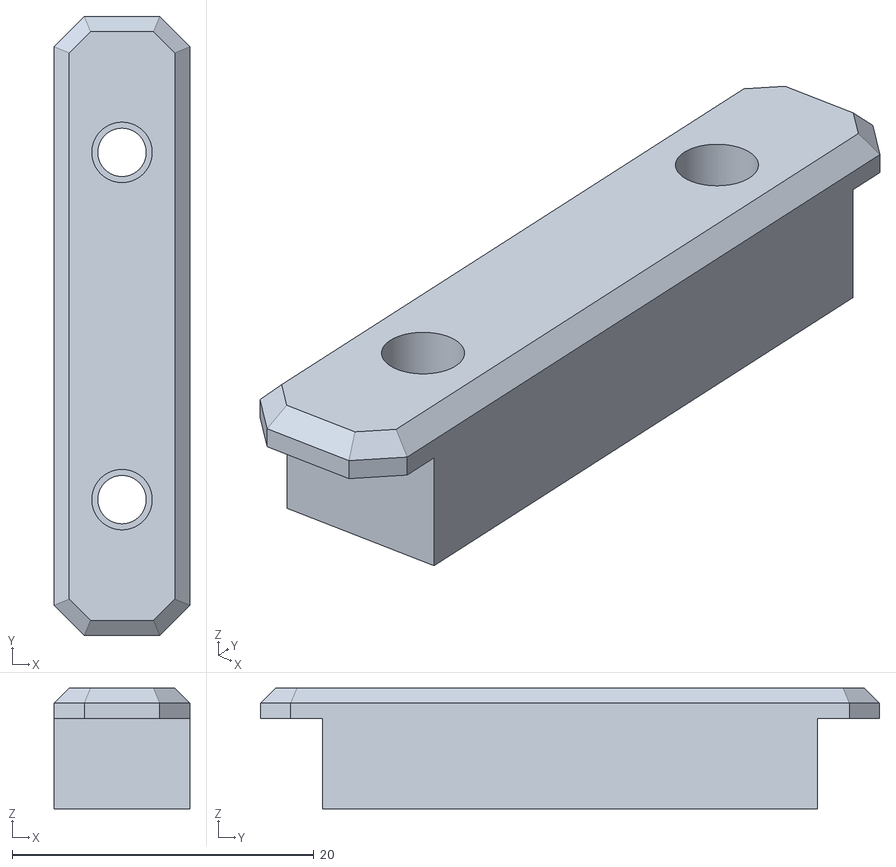
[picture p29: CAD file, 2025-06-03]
Accesorios decorativos/Accesorios OBJ o STL/20250319 Escalera camioncito-soporte arriba.obj
9.00 x 41.0 x 8.00

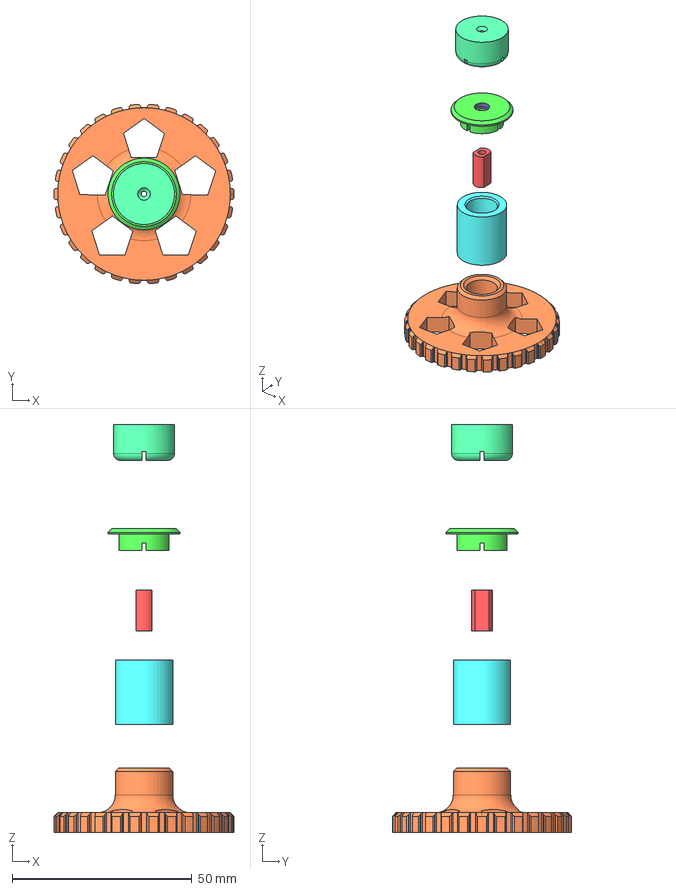
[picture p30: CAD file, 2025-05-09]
Accesorios ruedas amarillas/20250314 Accesorios ruedas amarillas.step
50.0 x 49.9 x 113.5 mm
centrador para taladrar ruedas
tapacubos
refuerzo brazo motor
separador rueda de repuesto
espaciador interno rueda

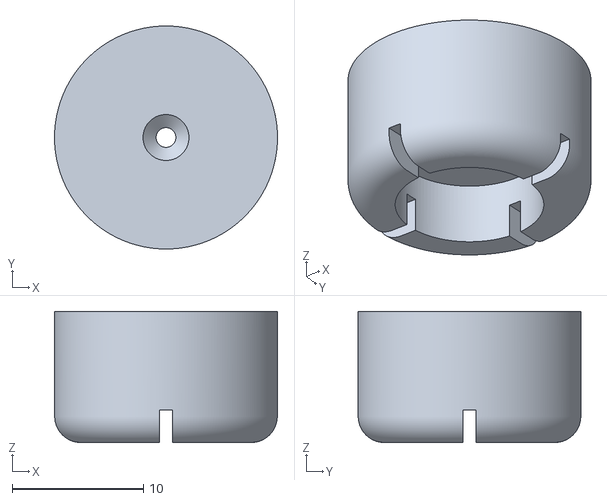
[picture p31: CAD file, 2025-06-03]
Accesorios ruedas amarillas/Ruedas amarillas OBJ o STL/20250314 Camión Share Horizons-centrador ruedas.obj
17.0 x 17.0 x 10.0

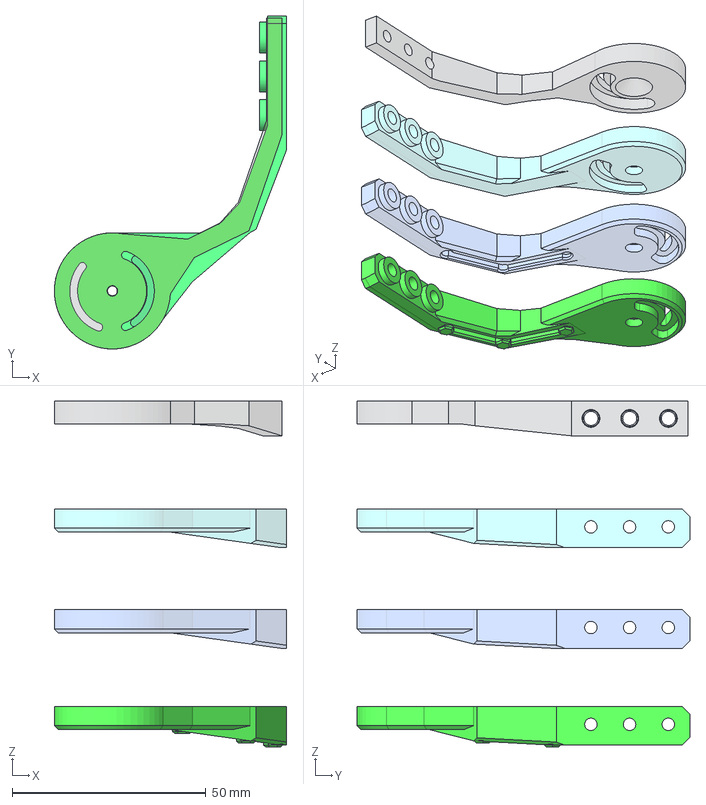
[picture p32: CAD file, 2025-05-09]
Brazos/20250509 Brazos modificados.step
60.0 x 86.0 x 89.4 mm
brazo nuevo con dibujo corredera corta opuesta (2)
brazo derecho nuevo reforzado corredera corta (1)
BRAZO_DER Original
Brazo derecho corredera corta opuesta y tornillos simulados (3)

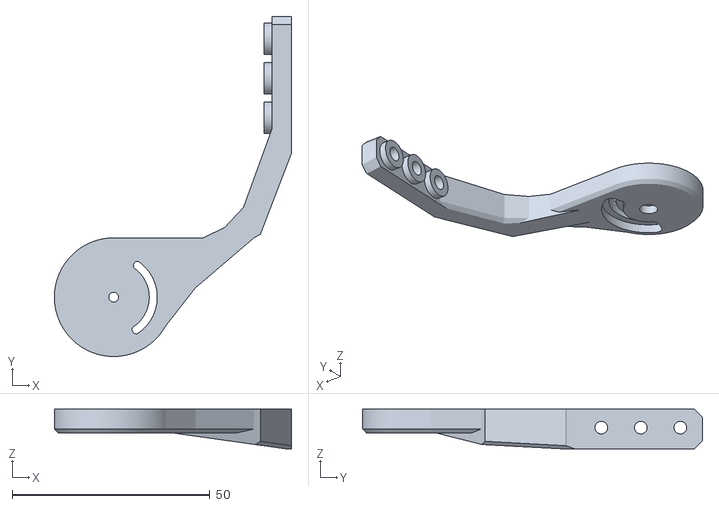
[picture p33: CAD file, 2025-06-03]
Brazos/Brazos OBJ o STL/20250316 Camion - reformas-brazo derecho nuevo.obj
60.0 x 86.0 x 10.0

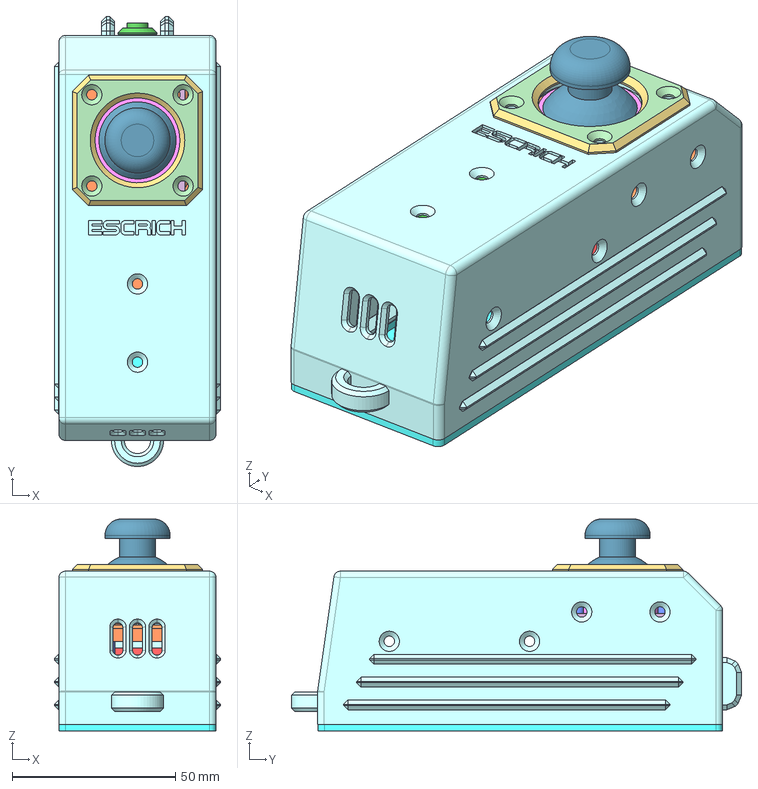
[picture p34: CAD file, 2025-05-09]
Mando a distancia/20250321 Mando a distancia camioncito.step
51.0 x 138.0 x 65.0 mm
embellecedor Joystick
base wemos
clip wemos
tapa mando
regulador de tensión
soporte joystick
interruptor
mando
joystick

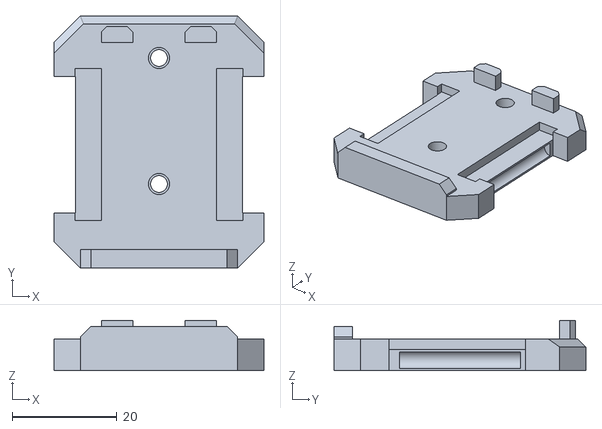
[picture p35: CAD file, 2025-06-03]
Mando a distancia/Mando OBJ o STL/20250321 Mando a distancia camioncito-base wemos.obj
40.0 x 48.0 x 9.60

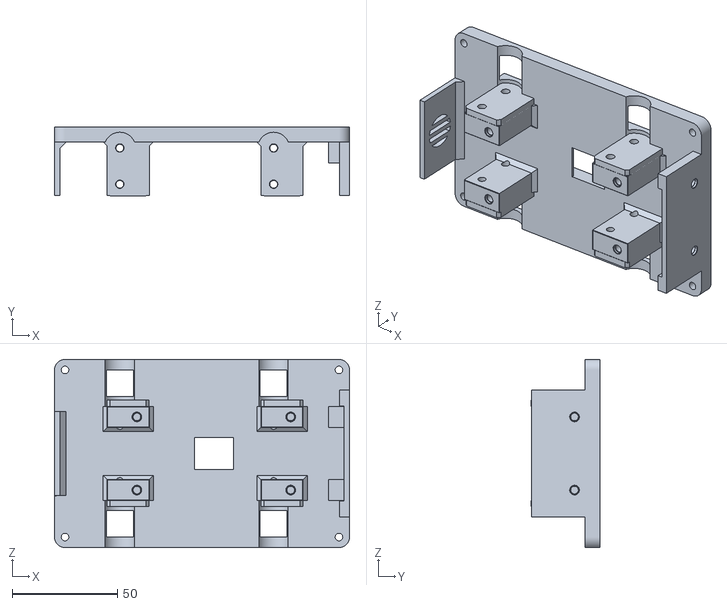
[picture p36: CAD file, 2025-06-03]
Reformas chasis/Chasis OBJ o STL/20250325 Camioncito, reforma chasis-chasis V1.obj
140.0 x 32.6 x 89.3

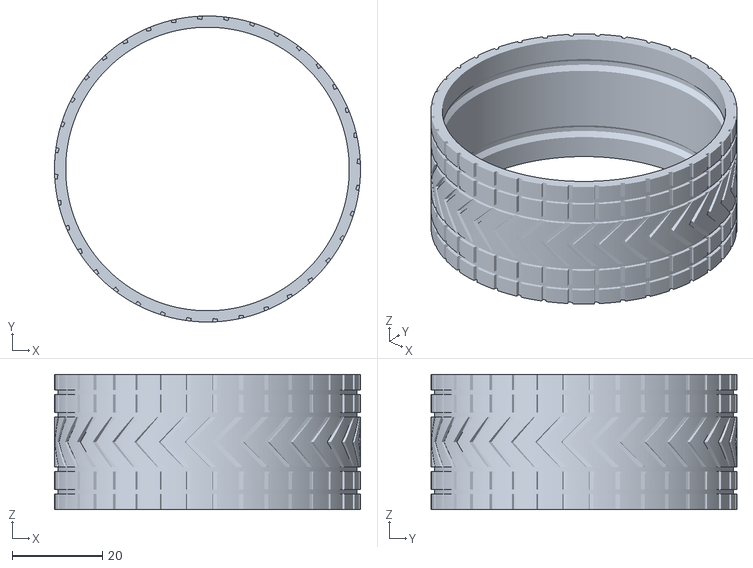
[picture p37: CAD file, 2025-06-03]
Ruedas y neumaticos nuevos/Ruedas nuevas OBJ o STL/20250317 Neumaticos nuevos-cubierta acabada.obj
68.0 x 68.0 x 30.0

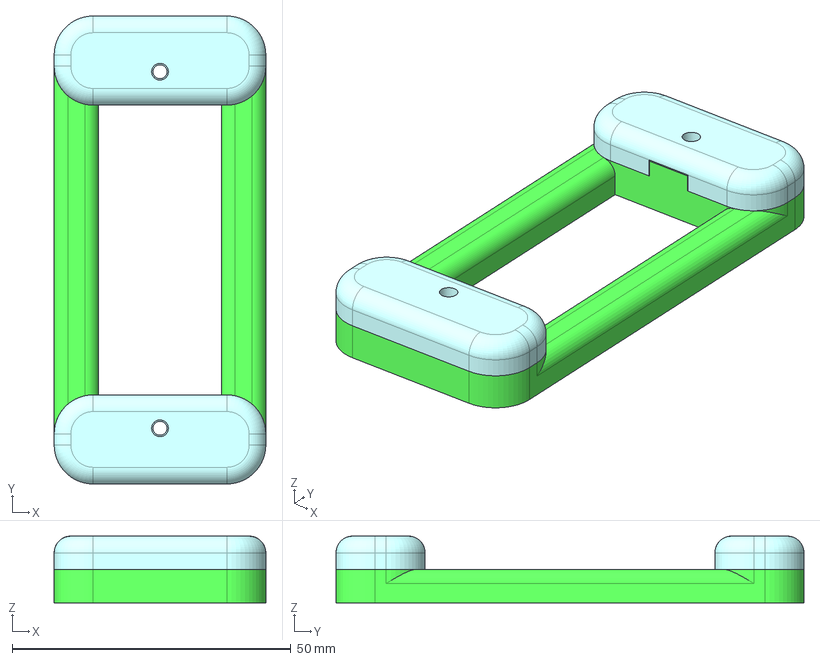
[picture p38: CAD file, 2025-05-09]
Accesorios decorativos/20250323 Rotativo luminoso.step
38.0 x 84.0 x 12.0 mm
frame
focos

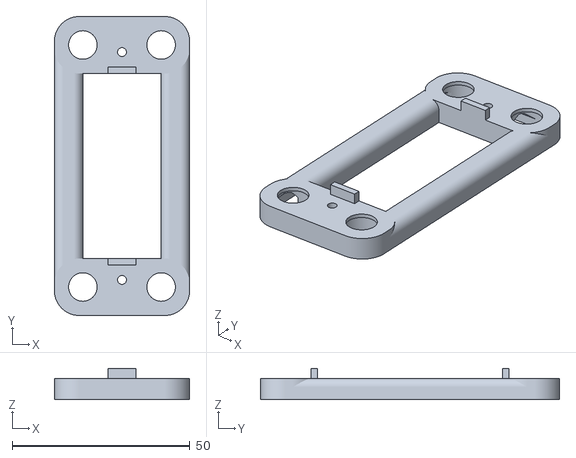
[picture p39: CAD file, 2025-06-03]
Accesorios decorativos/Accesorios OBJ o STL/20250323 Rotativo luminoso-frame.obj
38.0 x 84.0 x 8.80

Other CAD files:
Piezas no reformadas/CAMION - GUARDABARROS DCHO.step
Accesorios ruedas amarillas/Ruedas amarillas OBJ o STL/20250314 Camión Share Horizons-tapacubos.obj
Brazos/Brazos OBJ o STL/20250316 Camion - reformas - brazo con falsos tornillos.obj
Mando a distancia/Mando OBJ o STL/20250321 Mando a distancia camioncito-tapa mando.obj
Accesorios decorativos/20250319 Radar en camioncito.step
Accesorios decorativos/Accesorios OBJ o STL/20250316 Camion - reformas-pala con nombre.obj
Accesorios decorativos/Accesorios OBJ o STL/20250319 Escalera camioncito-escalera.obj
Accesorios decorativos/Accesorios OBJ o STL/20250319 Escalera camioncito-soporte abajo.obj
Accesorios decorativos/Accesorios OBJ o STL/20250319 Radar en camioncito-base radar.obj
Accesorios decorativos/Accesorios OBJ o STL/20250319 Radar en camioncito-radar.obj
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

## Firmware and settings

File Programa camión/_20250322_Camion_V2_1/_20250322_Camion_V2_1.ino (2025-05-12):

//***************************************************************************************************
//
//   Versión del programa para mis dos camiones, modificados desde el diseño original de
//   Share Horizons
//   Jose M. Escrich 20250322
//
//   En esta versión se ha cambiado, comprobado y corregido, la nomenclatura de todas
//   las variables de dirección y control de motor.
//   He recalculado los angulos de la dirección, haciendolos simetricos
//   Tambien se han añadido rutinas para el cambio de color de los leds en función de la dirección
//   Añadidos nuevos leds Neopixel en el canal 5
//   De momento he deshechado la idea de poner algún tipo de elemento acustico
//   He traducido la mayoría de los comentarios, para hacerlo mas didactico para los que están empezando
//
//   Gracias Share horizons, Gracias Creality
//
//***************************************************************************************************


// ----------------------------------------------------------------------------
// Incluye las librerías que vamos a necesitar utilizar en el proyecto
// ----------------------------------------------------------------------------

#include <esp_now.h>
#include <WiFi.h>
#include <ESP32Servo.h>
#include <Adafruit_NeoPixel.h>

#define LED_PIN 2  // led en Wemos D1 Mini ESP32, mismo pin en DOIT ESP32 Devkit V1
bool led = LOW;    // variable para encendido del led

#define SIGNAL_TIMEOUT 1000  // This is signal timeout in milli seconds. We will reset the data if no signal
unsigned long lastRecvTime = 0;

// ----------------------------------------------------------------------------
// SERVOS, crea como objetos los servos existentes, para poder ser controlados como servos
// ----------------------------------------------------------------------------
// En un ESP32 puedes definir hasta 16 servos

Servo BrazoDerecho;
Servo BrazoIzquierdo;

//Posiciones de los servos
int PosBrazoDerecho = 0;
int PosBrazoIzquierdo = 0;
#define tiempobrazos 300  // Tiempo de espera para los servos de los brazos

// ----------------------------------------------------------------------------
// Definición del canal Neopixel que controla la tira led de debajo del camión
// ----------------------------------------------------------------------------

#define PIN_WS2812B 21  // El pin GPIO21 del ESP32 conecta con tira de leds del tipo WS2812B, a la que llamaremos ws2812b
#define NUM_PIXELS 8    // 12 // Numero de LEDs (pixels) en una tira led del tipo WS2812B
//#define TIMERPIXELS 500

Adafruit_NeoPixel ws2812b(NUM_PIXELS, PIN_WS2812B, NEO_GRB + NEO_KHZ800);


// ----------------------------------------------------------------------------
// Nuevo canal Neopixel el equivalente a una tira de cuatro leds
// ----------------------------------------------------------------------------

#define ledsBomberosPin 5  // El pin GPIO5 del ESP32 conecta con tira deleds del tipo WS2812B, a la que llamaremos ledBomberos
#define numLeds 4          // Numero de LEDs (pixels) en una tira led del tipo WS2812B, en este caso son leds sueltos, conectados como una tira de 4 leds

Adafruit_NeoPixel ledBomberos(numLeds, ledsBomberosPin, NEO_GRB + NEO_KHZ800);

//  Variables para la nueva tira de cuatro leds
int contador = 0;       // Contador para hacer los avances de paso
int longitudPaso = 15;  // numero de pasos de contador para avanzar un paso
int pasoActual = 0;     // paso actual
bool parado = LOW;      // variable que muestra si el camión está parado o en marcha

// ----------------------------------------------------------------------------
// Definicion de pines de conexión
// ----------------------------------------------------------------------------
#define BrazoDerechoPin 32
#define BrazoIzquierdoPin 33

//MOTORES IZQUIERDA
#define MotorENAPinL 23   // Permiso de marcha y llegada señal PWM
#define MotorIN1PinLB 27  // Marcha atras
#define MotorIN2PinLF 12  // Marcha adelante
//MOTORES DERECHA
#define MotorENBPinR 22   // Permiso de marcha y llegada señal PWM
#define MotorIN3PinRF 18  // Marcha adelante
#define MotorIN4PinRB 19  // Marcha atras

// ============================================================================================

// Siguiendo mi costumbre, he usado las iniciales de las palabras
// adelante, atras, izquierda y derecha, en ingles, en cada simbolo
// Su significado es el siguiente:
// L : Left; Izquierda
// R : Right; Derecha
// F : Forward; Adelante
// B : Backwards; Atras

// La tabla de la verdad para las entradas,
// uno y dos para el grupo de motores de la Izquierda,
// es la siguiente:

//  IN 1  IN 2  MOTOR
//  LOW   LOW   PARADO
//  HIGH  LOW   ATRAS
//  LOW   HIGH  ADELANTE
//  HIGH  HIGH  PARADO

// o tres y cuatro para el grupo de motores de la derecha,
// es la siguiente:

//  IN 4  IN 3  MOTOR
//  LOW   LOW   PARADO
//  HIGH  LOW   ATRAS
//  LOW   HIGH  ADELANTE
//  HIGH  HIGH  PARADO

// ============================================================================================

// ----------------------------------------------------------------------------
// Definición de variables
// ----------------------------------------------------------------------------

int Conexionperdida = 0;

int angulo = 0;
int modulo = 0;
int Boton = 0;
int velmin = 80;     //Velocidad minima a la que se mueven los motores //  OJO al dato, reducir cuanto se pueda
int Potencia = 0;    //Potencia Joystick
int PotenciaMR = 0;  //Potencia motores derecha
int PotenciaML = 0;  //Potencia motores izquierda

// Variables usadas para generar las diferentes intermitencias
int intermitencia = LOW;           // señal que cambia de estado para usar como intermitente
unsigned long anteriorMillis = 0;  // guarda el valor del tiempo del ultimo cambio
const long intervalo = 200;        // intervalo para intermitencia en milisegundos

//Paquete de datos recibido del mando
struct PacketData {
  int AnguloValue;
  int ModuloValue;
  int switchPressed;
};
PacketData receiverData;

// ----------------------------------------------------------------------------
// Función de rellamada que se ejecuta cuando se reciben datos
// ----------------------------------------------------------------------------

void OnDataRecv(const esp_now_recv_info_t *info, const uint8_t *incomingData, int len) {
  if (len == 0) {
    return;
  }
  memcpy(&receiverData, incomingData, sizeof(receiverData));
  String inputData;
  inputData = inputData + "values " + receiverData.AnguloValue + "  " + receiverData.ModuloValue + "  " + receiverData.switchPressed;
  Serial.println(inputData);
  lastRecvTime = millis();
}

// ----------------------------------------------------------------------------
// Escalado de lso datos del Joystick
// ----------------------------------------------------------------------------

void MapeoJoystick() {
  angulo = receiverData.AnguloValue;
  modulo = receiverData.ModuloValue;
  if (modulo > 255) {
    modulo = 255;
  }
  Boton = receiverData.switchPressed;
}


// ----------------------------------------------------------------------------
//  Rutina para el control de los leds llamados de bomberos
// ----------------------------------------------------------------------------

void BucleBomberos() {

  if (Conexionperdida == 1) {
    if (intermitencia == HIGH) {
      ledBomberos.setPixelColor(0, ledBomberos.Color(255, 0, 0));  // rojo
      ledBomberos.setPixelColor(1, ledBomberos.Color(0, 0, 0));    // apagado
      ledBomberos.setPixelColor(2, ledBomberos.Color(0, 0, 0));    // apagado
      ledBomberos.setPixelColor(3, ledBomberos.Color(255, 0, 0));  // rojo
      ledBomberos.show();

    } else {
      ledBomberos.setPixelColor(0, ledBomberos.Color(0, 0, 0));    // apagado
      ledBomberos.setPixelColor(1, ledBomberos.Color(255, 0, 0));  // rojo
      ledBomberos.setPixelColor(2, ledBomberos.Color(255, 0, 0));  // rojo
      ledBomberos.setPixelColor(3, ledBomberos.Color(0, 0, 0));    // apagado
      ledBomberos.show();
    }
  } else {
    if (parado == HIGH) {
      if (intermitencia == HIGH) {
        ledBomberos.setPixelColor(0, ledBomberos.Color(0, 255, 0));  // verde
        ledBomberos.setPixelColor(1, ledBomberos.Color(0, 0, 0));    // apagado
        ledBomberos.setPixelColor(2, ledBomberos.Color(0, 0, 0));    // apagado
        ledBomberos.setPixelColor(3, ledBomberos.Color(0, 255, 0));  // verde
        ledBomberos.show();

      } else {
        ledBomberos.setPixelColor(0, ledBomberos.Color(0, 0, 0));    // apagado
        ledBomberos.setPixelColor(1, ledBomberos.Color(0, 255, 0));  // verde
        ledBomberos.setPixelColor(2, ledBomberos.Color(0, 255, 0));  // verde
        ledBomberos.setPixelColor(3, ledBomberos.Color(0, 0, 0));    // apagado
        ledBomberos.show();
      }

    } else {
      contador++;                      // Incrementamos el contador a cada ciclo de programa
      if (contador >= longitudPaso) {  // Comprobamos si ha contado los suficientes ciclos como para dar un paso
        pasoActual++;                  // Si ha contado suficiente, avanzamos un paso y
        contador = 0;                  // ponemos el contador de nuevo a cero
      }

      // Encendemos los leds en función del paso, (despues de haber definido mas de 10 pasos, lo dejo solo en dos, ya que el efecto luminoso es muy bueno)
      switch (pasoActual) {
        case 0:
          ledBomberos.setPixelColor(0, ledBomberos.Color(0, 0, 255));
          ledBomberos.setPixelColor(1, ledBomberos.Color(255, 0, 0));
          ledBomberos.setPixelColor(2, ledBomberos.Color(255, 0, 0));
          ledBomberos.setPixelColor(3, ledBomberos.Color(0, 0, 255));
          ledBomberos.show();
          break;
        case 1:
          ledBomberos.setPixelColor(0, ledBomberos.Color(255, 0, 0));
          ledBomberos.setPixelColor(1, ledBomberos.Color(0, 0, 255));
          ledBomberos.setPixelColor(2, ledBomberos.Color(0, 0, 255));
          ledBomberos.setPixelColor(3, ledBomberos.Color(255, 0, 0));
          ledBomberos.show();
          break;

        default: pasoActual = 0;  // Si el paso actual no coincide con lo que esperamos, porque sea mayor, lo volvemos a poner a cero
      }
    }
  }
}


// ----------------------------------------------------------------------------
// Rutina que genera todas las señales intermitentes para ser usadas donde se necesiten
// ----------------------------------------------------------------------------

void Intermitencias() {
  // Generación de señal intermitente

  unsigned long actualMillis = millis();

  if (actualMillis - anteriorMillis >= intervalo) {
    // guarda el momento en que se produjo el ultimo cambio
    anteriorMillis = actualMillis;
    // Si la señal está a uno la pone a cero, si está a cero la pone a uno
    if (intermitencia == LOW)
      intermitencia = HIGH;
    else
      intermitencia = LOW;
  }

}  // Fin de Intermitencias()

// ----------------------------------------------------------------------------

//GRAFCET NEOPIXEL

int PixelEstado = 0;

void PixelInicializar() {
  PixelEstado = 0;
}

void BucleNeopixel() {
  switch (PixelEstado) {
    case 0:  //Inicialización
             // ws2812b.clear();  // set all pixel colors to 'off'. It only takes effect if pixels.show() is called
             // ws2812b.show();   // update to the WS2812B Led Strip
             // PixelTimer = millis();  // No parece que se use
      PixelEstado = 1;
      break;

    case 1:
      if (Conexionperdida == 1) {
        for (int pixel = 0; pixel < NUM_PIXELS; pixel++) {  //red
          ws2812b.setPixelColor(pixel, ws2812b.Color(255, 0, 0));
          ws2812b.show();
        }
        PixelEstado = 2;
      } else {
        for (int pixel = 0; pixel < NUM_PIXELS; pixel++) {  //green
          ws2812b.setPixelColor(pixel, ws2812b.Color(0, 255, 0));
          ws2812b.show();
        }
        PixelEstado = 3;
      }
      break;

    case 2:
      if (Conexionperdida == 0) {
        PixelEstado = 1;
      }
      break;

    case 3:
      if (Conexionperdida == 1) {
        PixelEstado = 1;
      }
      break;
  }
}

// -------------------------------------------------------------------
// Rutinas para manejo de leds en función de la dirección, para 8 leds
// -------------------------------------------------------------------

void ledsAdelante() {

  borraLeds();
  ws2812b.setPixelColor(3, ws2812b.Color(0, 0, 255));
  ws2812b.setPixelColor(4, ws2812b.Color(0, 0, 255));
  ws2812b.show();
}

void ledsAtras() {

  borraLeds();
  ws2812b.setPixelColor(0, ws2812b.Color(0, 0, 255));
  ws2812b.setPixelColor(7, ws2812b.Color(0, 0, 255));
  ws2812b.show();
}

void ledsDerecha() {

  borraLeds();
  ws2812b.setPixelColor(1, ws2812b.Color(0, 0, 255));
  ws2812b.setPixelColor(2, ws2812b.Color(0, 0, 255));
  ws2812b.show();
}

void ledsIzquierda() {

  borraLeds();
  ws2812b.setPixelColor(5, ws2812b.Color(0, 0, 255));
  ws2812b.setPixelColor(6, ws2812b.Color(0, 0, 255));
  ws2812b.show();
}

// Poner leds en su estado inicial cuando paran los motores
void borraLeds() {
  for (int pixel = 0; pixel < NUM_PIXELS; pixel++) {  //verde
    ws2812b.setPixelColor(pixel, ws2812b.Color(0, 255, 0));
    ws2812b.show();
  }
}

// -------------------------------------------------------------------
//  Rutina de manejo de los brazos, un buen trabajo de Sharehorizons
// -------------------------------------------------------------------

//Grafcet Empujar

int EstadoEmpujar = 0;
int TimerEmpujar = 0;
bool empujando = false;

void InicializarEmpujar() {
  EstadoEmpujar = 0;
  TimerEmpujar = 0;
  empujando = false;
  PosBrazoDerecho = 70;
  PosBrazoIzquierdo = 180 - PosBrazoDerecho;
}

void MoverBrazos() {
  BrazoDerecho.write(PosBrazoDerecho);
  BrazoIzquierdo.write(PosBrazoIzquierdo);
}

void CambiarPosicionBrazos() {
  if (empujando == false) {
    empujando = true;
    PosBrazoDerecho = 170;
    PosBrazoIzquierdo = 180 - PosBrazoDerecho;
  } else {
    empujando = false;
    PosBrazoDerecho = 70;
    PosBrazoIzquierdo = 180 - PosBrazoDerecho;
  }
}

void Empujar() {

  switch (EstadoEmpujar) {

    case 0:  //ESPERAMOS A QUE PULSEN EL SWITCH
      MoverBrazos();
      if (receiverData.switchPressed == true) {
        EstadoEmpujar = 1;
      }

      break;

    case 1:  //HAN PULSADO EL SWITCH
      CambiarPosicionBrazos();
      MoverBrazos();
      TimerEmpujar = millis();
      EstadoEmpujar = 2;

      break;

    case 2:  //ESPERAMOS QUE LOS SERVOS SE MUEVAN

      MoverBrazos();

      if (millis() >= TimerEmpujar + tiempobrazos) {
        TimerEmpujar = 0;
        EstadoEmpujar = 0;
      }

      break;
  }
}


//GRAFCET MOVIMIENTO
int EstadoMovimiento = 0;
int TimerMovimiento = 0;

void IniMovimiento() {
  EstadoMovimiento = 0;
  TimerMovimiento = 0;
}

// ----------------------------------------------------------------------------
// Rutinas de movimiento en función del angulo que les llega desde el Joystick
// ----------------------------------------------------------------------------

void Movimiento() {
  // He cambiado el reparto de angulos haciendolos simetricos, que por alguna razón no lo eran
  parado = LOW;  // reseteamos el flag que indica si el camión está parado o en marcha

  switch (EstadoMovimiento) {

    case 0:  //Inicializamos las variables
      EstadoMovimiento = 1;
      break;

    case 1:  //Esperemos a que muevan el joystick
      if (modulo > 0) {
        Potencia = map(modulo, 0, 255, velmin, 255);
        if (angulo >= 65 && angulo <= 115) {  //Z1: ADELANTE
          PotenciaML = Potencia;
          PotenciaMR = Potencia;
          adelante();
          ledsAdelante();                          // Enciende en azul los leds de marcha adelante
        } else if (angulo >= 25 && angulo < 65) {  //Z2: DIAGONAL DELANTE DERECHA
          PotenciaML = Potencia;
          PotenciaMR = velmin;
          adelante();
          ledsDerecha();                          // Enciende en azul los leds de girar a derecha
        } else if (angulo >= 0 && angulo < 25) {  //Z3: DERECHA
          PotenciaML = Potencia;
          PotenciaMR = 0;
          adelante();
          ledsDerecha();             // Enciende en azul los leds de girar a derecha
        } else if (angulo >= 335) {  //Z3: DERECHA
          PotenciaML = Potencia;
          PotenciaMR = 0;
          adelante();
          ledsDerecha();                             // Enciende en azul los leds de girar a derecha
        } else if (angulo > 115 && angulo <= 155) {  //Z8: DIAGONAL DELANTE IZQUIERDA
          PotenciaML = velmin;
          PotenciaMR = Potencia;
          adelante();
          ledsIzquierda();                           // Enciende en azul los leds de girar a izquierda
        } else if (angulo > 155 && angulo <= 215) {  //Z7: IZQUIERDA
          PotenciaML = 0;
          PotenciaMR = Potencia;
          adelante();
          ledsIzquierda();                           // Enciende en azul los leds de girar a izquierda
        } else if (angulo > 215 && angulo <= 245) {  //Z6: DIAGONAL DETRAS IZQUIERDA
          PotenciaML = velmin;
          PotenciaMR = Potencia;
          atras();
          ledsIzquierda();                           // Enciende en azul los leds de girar a izquierda
        } else if (angulo > 245 && angulo <= 295) {  //Z5: ATRAS
          PotenciaML = Potencia;
          PotenciaMR = Potencia;
          atras();
          ledsAtras();                              // Enciende en azul los leds de marcha atras
        } else if (angulo > 295 && angulo < 335) {  //Z4: DIAGONAL DETRAS DERECHA
          PotenciaML = Potencia;
          PotenciaMR = velmin;
          atras();
          ledsDerecha();  // Enciende en azul los leds de girar a derecha
        }
      } else {  //PARADO
        parar();
        borraLeds();
        parado = HIGH;  // Activamos el flag que nos dice que estamos parados
      }
      break;
  }
}

// ----------------------------------------------------------------------------
// Rutinas de marcha y dirección de los motores
// ----------------------------------------------------------------------------

void MLparado() {  //Motores Izquierda Parados
  analogWrite(MotorENAPinL, 0);
  digitalWrite(MotorIN1PinLB, LOW);
  digitalWrite(MotorIN2PinLF, LOW);
}
void MRparado() {  //Motores Derecha Parados
  analogWrite(MotorENBPinR, 0);
  digitalWrite(MotorIN3PinRF, LOW);
  digitalWrite(MotorIN4PinRB, LOW);
}
void MLadelante() {  //Motores Izquierda adelante
  analogWrite(MotorENAPinL, PotenciaML);
  digitalWrite(MotorIN1PinLB, LOW);
  digitalWrite(MotorIN2PinLF, HIGH);
}
void MRadelante() {  //Motores Derecha adelante
  analogWrite(MotorENBPinR, PotenciaMR);
  digitalWrite(MotorIN3PinRF, HIGH);
  digitalWrite(MotorIN4PinRB, LOW);
}
void MLatras() {  //Motores Izquierda atras
  analogWrite(MotorENAPinL, PotenciaML);
  digitalWrite(MotorIN1PinLB, HIGH);
  digitalWrite(MotorIN2PinLF, LOW);
}
void MRatras() {  //Motores Derecha atras
  analogWrite(MotorENBPinR, PotenciaMR);
  digitalWrite(MotorIN3PinRF, LOW);
  digitalWrite(MotorIN4PinRB, HIGH);
}
void parar() {  //Parar camión
  MRparado();
  MLparado();
}
void adelante() {  //Camión adelante
  MRadelante();
  MLadelante();
}
void atras() {  //Camión atras
  MRatras();
  MLatras();
}
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
void loop() {
  // Aquí se pone el código que ha de ejecutarse, repetidamente, a cada ciclo de programa:

  // ----------------------------------------------------------------------------
  // Comprobación de pérdida de señal.
  // ----------------------------------------------------------------------------
  unsigned long now = millis();

  if (now - lastRecvTime > SIGNAL_TIMEOUT)  // SE HA PERDIDO LA CONEXION CON EL MANDO
  {
    Conexionperdida = 1;
    parar();  //PARAR MOTORES
    IniMovimiento();
    Serial.print("MANDO OUT\n");
  } else {
    Conexionperdida = 0;
    MapeoJoystick();
    Movimiento();
    Empujar();
  }

  // ----------------------------------------------------------------------------
  //  Llamadas a diferentes sub-rutinas
  // ----------------------------------------------------------------------------

  BucleNeopixel();
  BucleBomberos();
  Intermitencias();

  // ----------------------------------------------------------------------------
  // Salida de información de proceso por pantalla
  // ----------------------------------------------------------------------------

  //  /*
  // estos son mis datos en pantalla
  // Serial.println("");
  Serial.print("Ángulo: ");
  Serial.print(angulo);
  Serial.print("  Módulo: ");
  Serial.print(modulo);
  Serial.print("  Botón: ");
  Serial.print(Boton);
  Serial.print("  PotenciaML: ");
  Serial.print(PotenciaML);
  Serial.print("  PotenciaMR: ");
  Serial.print(PotenciaMR);
  Serial.print("  Potencia: ");
  Serial.print(Potencia);
  Serial.print("  velmin: ");
  Serial.print(velmin);
  Serial.print("  Paso actual: ");
  Serial.print(pasoActual);
  Serial.print("  contador: ");
  Serial.print(contador);
  Serial.print("  parado: ");
  Serial.print(parado);


  Serial.println("");

  // ----------------------------------------------------------------------------
  // Muestra la Mac address
  // ----------------------------------------------------------------------------

  //Quita la linea justo debajo si quieres ver la mac address en el monitor serie, recuerda ponerlas despues para no perder tiempo de proceso
  /*
  Serial.println("Mac address del dispositivo:");
  Serial.println(WiFi.macAddress());
  */
  //Quita la linea justo encima si quieres ver la mac address en el monitor serie, recuerda ponerlas despues para no perder tiempo de proceso

  // */

  // ----------------------------------------------------------------------------
  // Encendido del led azul de la placa
  // ----------------------------------------------------------------------------
  if (led == LOW) {
    led = HIGH;
  } else {
    led = LOW;
  }
  digitalWrite(LED_PIN, led);
  // ----------------------------------------------------------------------------
}

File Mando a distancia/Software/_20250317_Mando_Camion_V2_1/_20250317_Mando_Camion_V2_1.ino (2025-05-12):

// -------------------------------------------------------------------------------
//
//  Programa para el mando a distancia de los camiones de Sharehorizons
//
//  emite usando el protocolo ESPNOW al receptor que es el camión
//
//  Totalmente operacional en ambos modelos de mandos a distancia, 
//  posiblemente necesite retocar algunos parametros, 
//  en función de la posición fisica del Joystick, respecto al propio mando en si.
//
//  Ligeramente reformado por Jose M. Escrich - 20250512
//
// -------------------------------------------------------------------------------


// Bibliotecas a incluir
#include <esp_now.h>
#include <WiFi.h>
#include <math.h>

// Definición de pines
#define X_AXIS_PIN 32 // Los numeros de pin se mantienen, aunque las funciones de X e Y se intercambian
#define Y_AXIS_PIN 33 // Los numeros de pin se mantienen, aunque las funciones de X e Y se intercambian
#define SWITCH_PIN 25 // Interruptor del Joystick, se activa al pulsarlo
#define LED_PIN 2     // led en Wemos D1 Mini ESP32, mismo pin en DOIT ESP32 Devkit V1

// MAC DEL RECEPTOR
// Comentar la linea que no se use
//uint8_t receiverMacAddress[] = { 0xAA,0xAA,0xAA,0xAA,0xAA,0xAA };  // AA:AA:AA:AA:AA:AA // Escrich // 20250317
// AA:AA:AA:AA:AA:AA Camión de bomberos

uint8_t receiverMacAddress[] = { 0xAA,0xAA,0xAA,0xAA,0xAA,0xAA };  // AA:AA:AA:AA:AA:AA // Escrich // 20250317
// AA:AA:AA:AA:AA:AA Camión con radar


// Definición de variables
double angulo;
double opuesto;
double continuo;
double modulo;

double ejeX;  // Usados solo para debug
double ejeY;  // Usados solo para debug

bool led = LOW;  // variable para encendido del led que va en la placa

// Definición de la estructura de datos, que envía los valores del Joystick al camión

struct PacketData {
  int AnguloValue;
  int ModuloValue;
  int switchPressed;
};
PacketData data;

//This function is used to map 0-4095 joystick value to 0-254. hence 127 is the center value which we send.
//It also adjust the deadband in joystick.
//Jotstick values range from 0-4095. But its center value is not always 2047. It is little different.
//So we need to add some deadband to center value. in our case 1800-2200. Any value in this deadband range is mapped to center 127.

double MapeoJoystick(int valor) {

  if (valor >= 2200) {
    valor = map(valor, 2200, 4095, 0, 255);
  } else if (valor <= 1800) {
    valor = map(valor, 1800, 0, 0, -255);
  } else {
    valor = 0;
  }

  return valor;
}

/*
// Esta parte es el original ## 20250321 # Escrich
// He cambiado de lugar el signo "-" para invertir ambos ejes, ya que me viene mejor
// la posición fisica del joystick, con los cables mirando hacia el centro del mando
double MapeoJoystick(int valor) {

  if (valor >= 2200) {
    valor = map(valor, 2200, 4095, 0, -255);
  } else if (valor <= 1800) {
    valor = map(valor, 1800, 0, 0, 255);
  } else {
    valor = 0;
  }

  return valor;
}
*/

// callback when data is sent

void OnDataSent(const uint8_t *mac_addr, esp_now_send_status_t status) {
  /*
  Serial.print("\r\nLast Packet Send Status:\t ");
  Serial.println(status);
  Serial.println(status == ESP_NOW_SEND_SUCCESS ? "Message sent" : "Message failed");
  */
}

void setup() {
  Serial.begin(115200);
  WiFi.mode(WIFI_STA);
  delay(1000);

  // Init ESP-NOW
  if (esp_now_init() != ESP_OK) {
    Serial.println("Error initializing ESP-NOW");
    return;
  } else {
    Serial.println("Succes: Initialized ESP-NOW");
  }

  esp_now_register_send_cb(OnDataSent);

  // Register peer
  //esp_now_peer_info_t peerInfo; // Linea original
  esp_now_peer_info_t peerInfo = {}; // Añadido en la ultima versión de Shere horizons para evitar bloqueos
  memcpy(peerInfo.peer_addr, receiverMacAddress, 6);
  peerInfo.channel = 0;
  peerInfo.encrypt = false;

  // Add peer
  if (esp_now_add_peer(&peerInfo) != ESP_OK) {
    Serial.println("Failed to add peer");
    return;
  } else {
    Serial.println("Succes: Added peer");
  }

  pinMode(SWITCH_PIN, INPUT_PULLUP);
  pinMode(LED_PIN, OUTPUT);

} // Fin de setup

void loop() {
  data.switchPressed = false;

  if (digitalRead(SWITCH_PIN) == LOW) {
    data.switchPressed = true;
  }

  opuesto = MapeoJoystick(analogRead(X_AXIS_PIN));
  continuo = MapeoJoystick(analogRead(Y_AXIS_PIN));
  angulo = atan2(opuesto, continuo);
  angulo = 180 * (double)angulo / PI;
  if (angulo < 0) {
    angulo = angulo + 360;
  }
  modulo = sq(opuesto) + sq(continuo);
  modulo = sqrt(modulo);

  if (modulo <= 30) {
    modulo = 0;
  }
  if (modulo > 255) {
    modulo = 255;
  }

  data.AnguloValue = int(trunc(angulo));
  data.ModuloValue = int(trunc(modulo));


  // Comentar tras la puesta en marcha // Escrich
  /*
  // Esta parte es el original
  Serial.print("Ángulo: ");
  Serial.println(data.AnguloValue);
  Serial.print("Módulo: ");
  Serial.println(data.ModuloValue);
  Serial.print("Botón: ");
  Serial.println(data.switchPressed);
*/

  ejeX = analogRead(X_AXIS_PIN);  // Usados solo para debug
  ejeY = analogRead(Y_AXIS_PIN);  // Usados solo para debug

  // /*
  // estos son mis datos en pantalla
  //Serial.println("");
  Serial.print("Ángulo: ");
  Serial.print(data.AnguloValue);
  Serial.print("  Módulo: ");
  Serial.print(data.ModuloValue);
  Serial.print("  Botón: ");
  Serial.print(data.switchPressed);
  Serial.print("  Opuesto X mapeado: ");
  Serial.print(opuesto);
  Serial.print("  Continuo Y mapeado: ");
  Serial.print(continuo);
  Serial.print("  Eje X: ");
  Serial.print(ejeX);
  Serial.print("  Eje Y: ");
  Serial.print(ejeY);

  Serial.println("");
  // */


  esp_err_t result = esp_now_send(receiverMacAddress, (uint8_t *)&data, sizeof(data));
  if (result == ESP_OK) {
    //Serial.println("Sent with success"); // Texto en el terminal eliminado por claridad
  } else {
    // Serial.println("Error sending the data"); // Texto en el terminal eliminado por claridad
  }
  delay(150);  // # 200 # Reducir este valor hace que los datos de el mando se envían mas veces por segundo

  // Encendido del led azul de la placa
  // ===================================
  if (led == LOW) {
    led = HIGH;
  } else {
    led = LOW;
  }
  digitalWrite(LED_PIN, led);
  // ===================================


}  // Fin de loop

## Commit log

2025-05-09 First load
    [20250314 Accesorios ruedas amarillas.step, 20250319 Escalera camioncito.step, 20250319 Radar en camioncito.step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]
2025-05-09 steps folder deleted
    [20250314 Accesorios ruedas amarillas.step, 20250319 Escalera camioncito.step, 20250319 Radar en camioncito.step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]
2025-05-10 Create 20250321 Proyecto camión Sharehorizons, Notas de trabajo Escrich.pdf
2025-05-10 Create 20250325 Camioncito, reforma chasis-placa motores.step
    [20250325 Camioncito, reforma chasis-placa motores.step]
2025-05-10 more parts
    [20250509 Tapa leds gruesa.stl, CAMION - GUARDABARROS DCHO.step, CAMION - GUARDABARROS IZQDO.step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]
2025-05-10 Led cover description added
2025-05-10 Reforma chasis updated
    [20250325 Camioncito, reforma chasis-placa motores.step]
2025-05-10 Update 20250321 Proyecto camión Sharehorizons, Notas de trabajo Escrich.pdf
2025-06-03 3D Print files added
    [20250314 Camión Share Horizons-centrador ruedas.obj, 20250314 Camión Share Horizons-placa motores.obj, 20250314 Camión Share Horizons-refuerzo brazo motor.obj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]
